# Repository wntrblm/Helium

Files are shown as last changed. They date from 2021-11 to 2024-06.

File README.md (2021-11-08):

# Winterbloom Helium

Helium is a precision buffered multiple and precision adder for Eurorack.

More details available at https://winterbloom.com/shop/helium

## Repository layout

This repository contains the hardware design files and user guide for Helium:

- **hardware/** contains the hardware design files for the mainboard and blank panel. These are all created using KiCAD.
- **user_guide/** contains the user's guide source files. These are written in Markdown and published using MkDocs.

## License and contributing

Helium is open-source hardware and software, however, licensing a project like this is a little complicated. Please take a chance to review the [LICENSE](LICENSE.md) file.

We welcome contributions! Please read our [Code of Conduct](CODE_OF_CONDUCT.md) first.

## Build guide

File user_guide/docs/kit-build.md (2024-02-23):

---
title: Kit build guide
---

# Build

Welcome to the build guide for Helium's DIY kit. We hope you have a great time putting this module together and a wonderful time using it.

Please **read all instructions** thoroughly before starting. If you have questions or run into trouble please reach out to us on [discord] or drop us an email at support@winterbloom.com.

Some soldering experience is helpful but not required. If it's your first time soldering we recommend reading through [Adafruit's guide to excellent soldering](https://learn.adafruit.com/adafruit-guide-excellent-soldering).

This build takes around **one hour** to complete.

[discord]: https://discord.gg/UpfqghQ

## Tools required

Before you begin, make sure that you've got:

-   Safety glasses. Yes, **really**. A pair like [these][safety glasses] are fine.
-   Proper ventilation, like this [small filtered fan](https://a.co/d/eUfPCRO).
-   A **temperature-controlled** soldering iron, like this [Hakko] or the [Pinecil]. It is very important to use a temperature-controlled iron, since unregulated irons can easily get hot enough to damage components. You should set your iron temperature based on your solder manufacturer's recommendations.
-   Solder. We recommend [Adafruit's SAC305 solder][adafruit solder] or [Kester 275 K100LD].

!!! question "Flux"
    We suggest using solder with "no clean" flux. If you use a different kind of flux, be sure to carefully clean the flux residue off based on the guidelines provided by the manufacturer of your solder. Take special care with the LEDs and potentiometers, as they can be damaged by water and flux cleaners.

[safety glasses]: https://a.co/d/dMXvPP6
[tweezers]: https://www.adafruit.com/product/422
[Hakko]: https://www.adafruit.com/product/1204
[Pinecil]: https://pine64.com/product/pinecil-smart-mini-portable-soldering-iron/
[adafruit solder]: https://www.adafruit.com/product/734
[Kester 275 K100LD]: https://www.kester.com/products/product/275-flux-cored-wire
[flux pen]: https://www.sra-solder.com/sra-312-no-clean-flux-pen-refillable

## Kit contents

Your kit should contain the following items. If any are missing please email us at support@winterbloom.com.

<winter-image-map src="../images/kit.svg">
    <winter-image-map-item id="mainboard">Mainboard</winter-image-map-item>
    <winter-image-map-item id="panel">Front panel</winter-image-map-item>
    <winter-image-map-item id="jacks">1/8" jacks (16)</winter-image-map-item>
    <winter-image-map-item id="nuts">Hex nuts for the 1/8" jacks (16)</winter-image-map-item>
    <winter-image-map-item id="power-header">Eurorack power header (1)</winter-image-map-item>
    <winter-image-map-item id="rubber-bands">Rubber bands (2)</winter-image-map-item>
</winter-image-map>

- (1) Mainboard
- (1) Front panel
- (16) 1/8" jacks
- (16) Hex nuts for the 1/8" jacks
- (1) Eurorack power header
- (2) Rubber bands

## Soldering the power header

Your first task is to place and solder the power header to the mainboard.

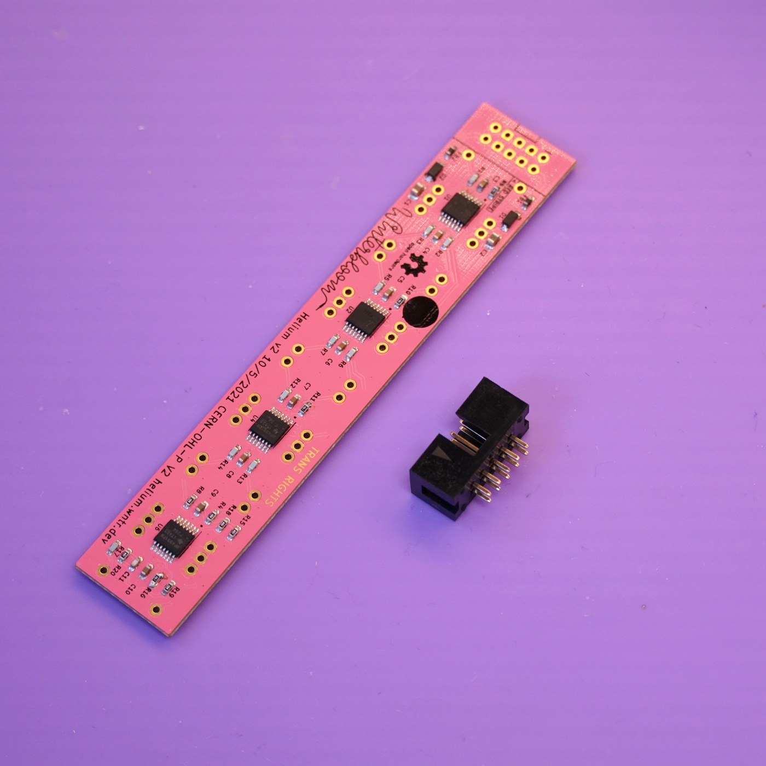
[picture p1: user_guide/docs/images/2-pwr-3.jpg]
The mainboard and power header


Place the power header onto the back side of the mainboard, being careful to align the notch in the header with the drawing on the board. The power header fits snugly, so you might have to give it a little pressure to push it all the way in.

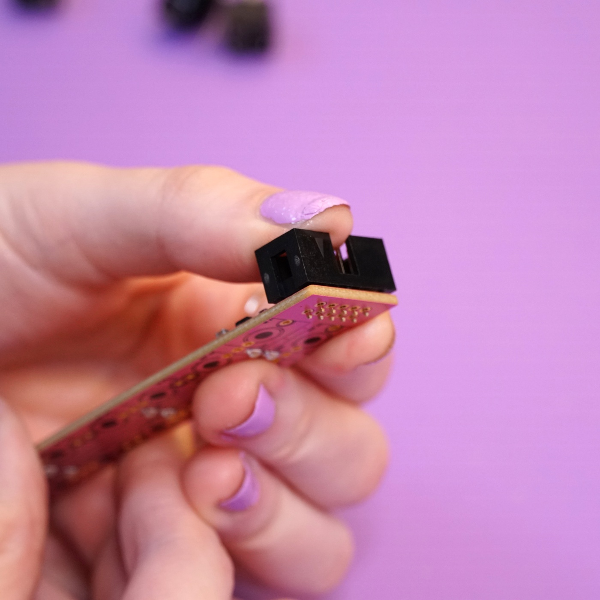
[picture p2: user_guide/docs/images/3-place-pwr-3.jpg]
The power header placed on to the mainboard


Flip the board over to the front side and solder the header's 10 pins.

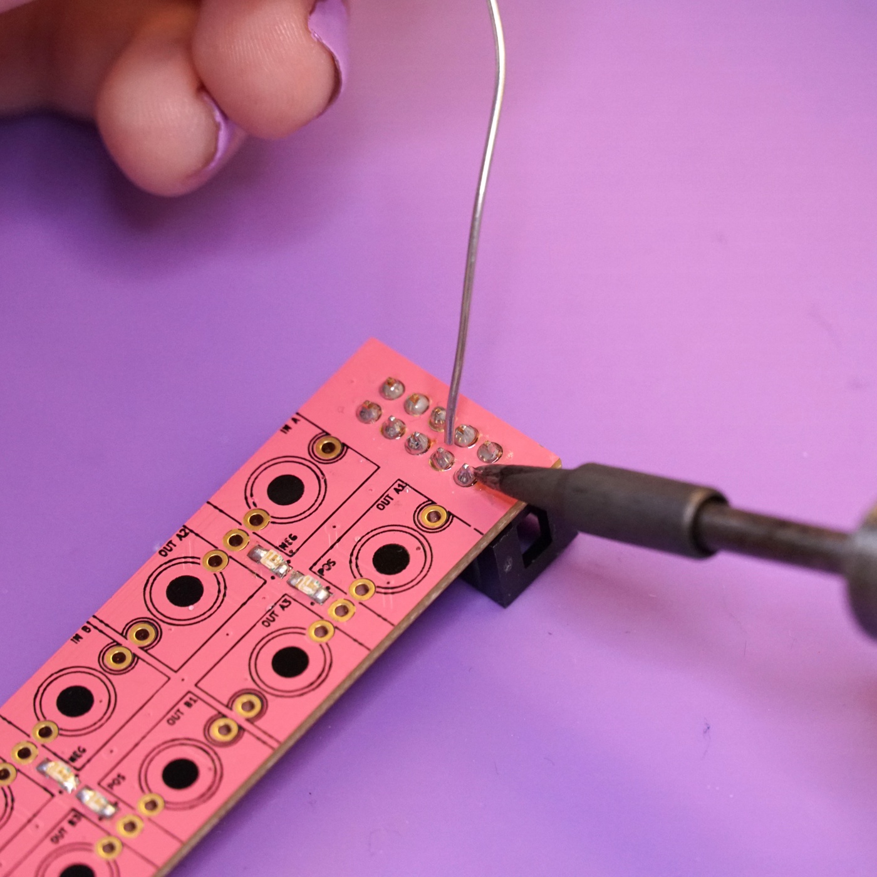
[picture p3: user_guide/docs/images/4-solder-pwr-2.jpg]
The power header being soldered to the mainboard


## Placing the jacks

Next up is placing the sixteen jacks on the front side of the mainboard. Start by placing the first jack on in the space labeled `In A`. Place it according to the drawing on the board, with the third, bendy leg going into the adjacent hole.

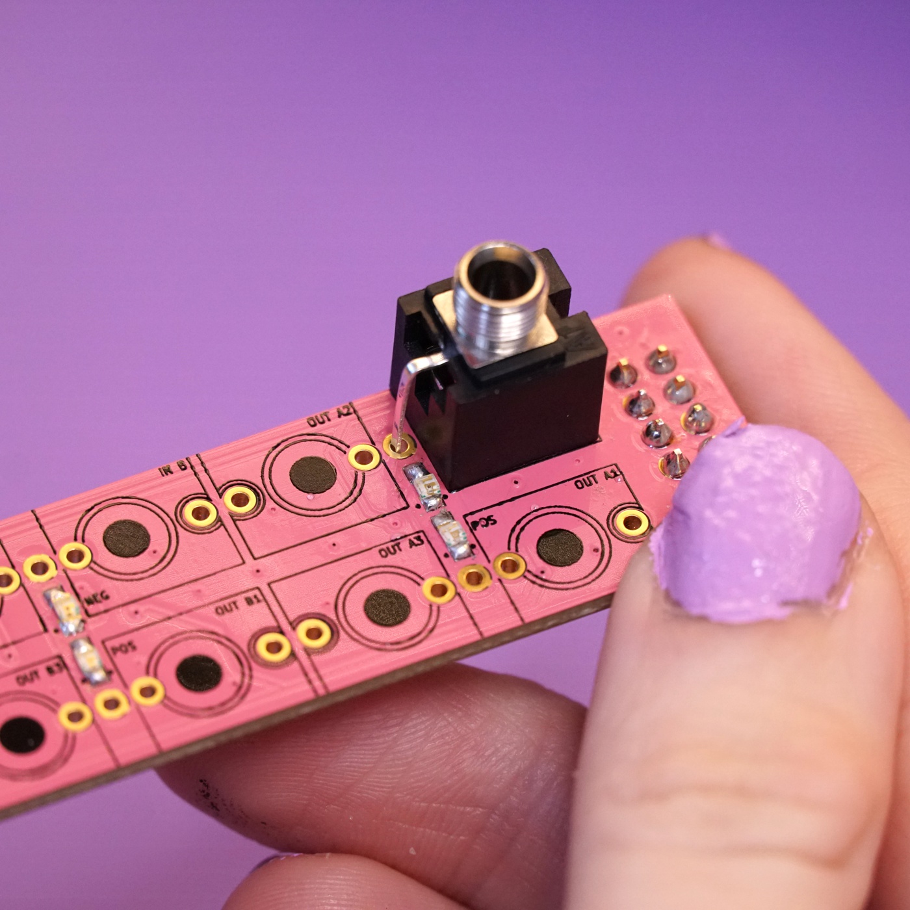
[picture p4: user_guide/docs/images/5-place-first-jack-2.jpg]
The first jack placed on the front side of the mainboard, over the place labeled "In A"


The second jack is a bit trickier. Place it into the space labeld `Out A2` but in the **opposite** orientation of the first jack. Place the third leg into the **same** hole as the first jack's third leg.

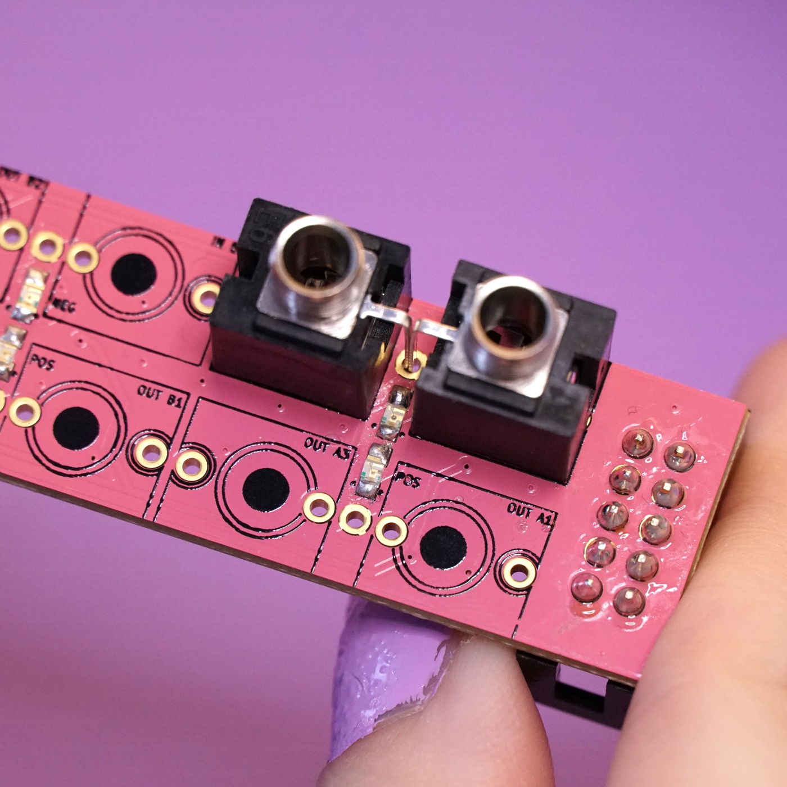
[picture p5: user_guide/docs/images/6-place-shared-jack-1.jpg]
The second jack placed on the front side of the mainboard, over the place labeled "Out A2", with its third leg sharing the same hole as the first jack


Continue this pattern for the third and fourth jacks in the spaces labeled `In B` and `Out B2`. The third and fourth jacks will have their third legs placed into the same hole.

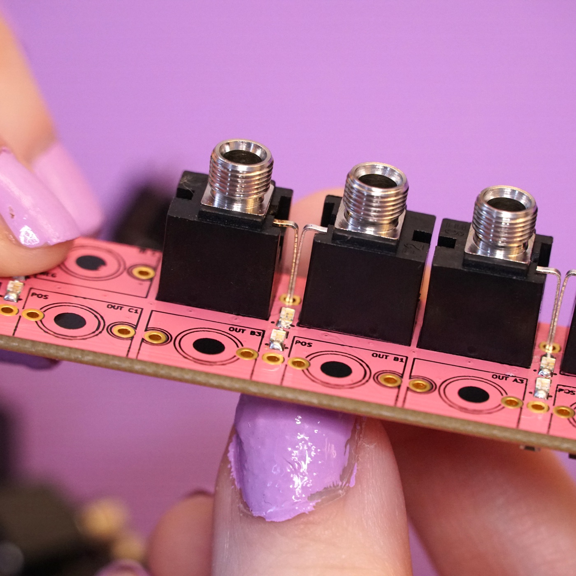
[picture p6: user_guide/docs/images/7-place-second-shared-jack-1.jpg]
The third and fourth jacks placed with them sharing a single hole for their third legs


Likewise for the remaining jacks. Continue the pattern of alternating orientation and sharing the hole for the third leg until all jacks are placed.

<winter-carousel>
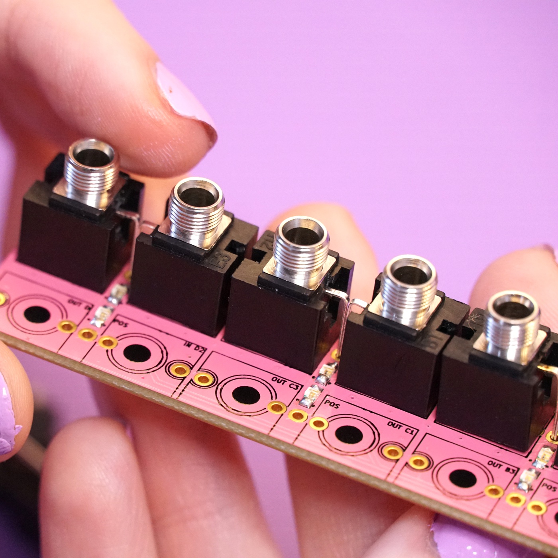
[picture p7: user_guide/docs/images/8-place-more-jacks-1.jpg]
The remaining jacks on the left side of the board all placed
    
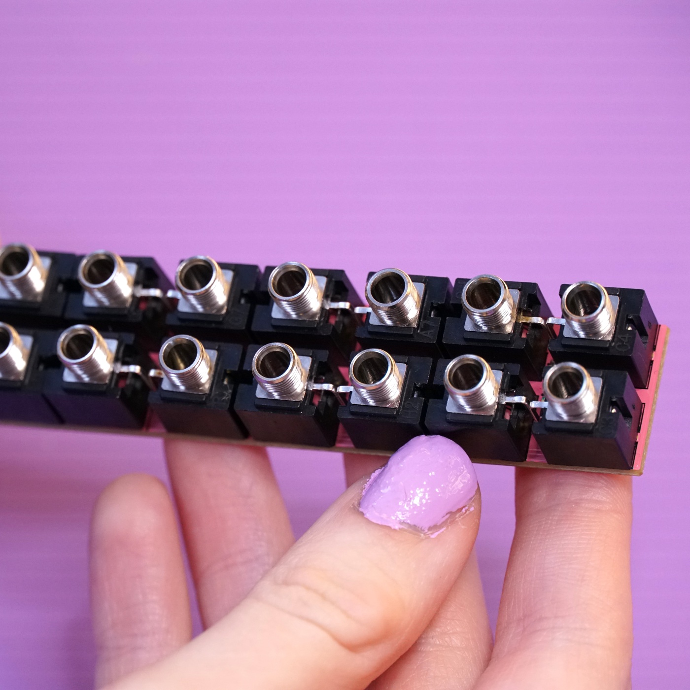
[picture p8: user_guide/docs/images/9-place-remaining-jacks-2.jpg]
All jacks on the board placed
    
</winter-carousel>

## Using the front panel as a jig

Since the jacks need to peek through the front panel, you can use it as a jig to make sure everything stays in the right place while soldering. Carefully line up the front panel's holes with the jacks and push the front panel on.

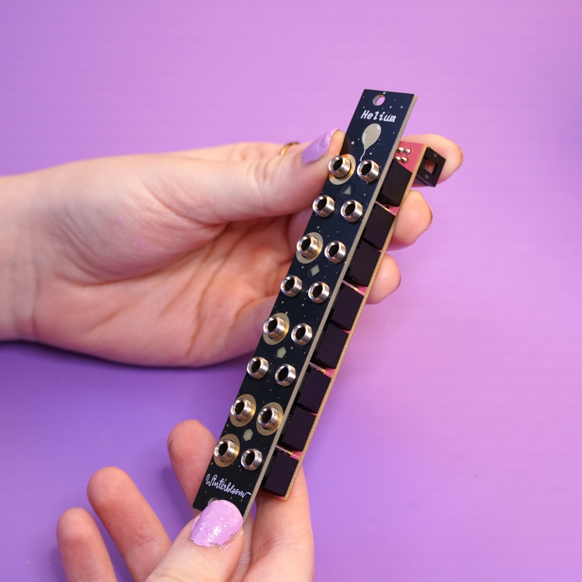
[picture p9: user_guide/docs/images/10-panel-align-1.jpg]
The front panel placed over the jacks


Then, use the two rubber bands to temporarily hold the front panel on while you're working on it. You'll need to double- or triple- over the rubber band to get it tight.

<winter-carousel>
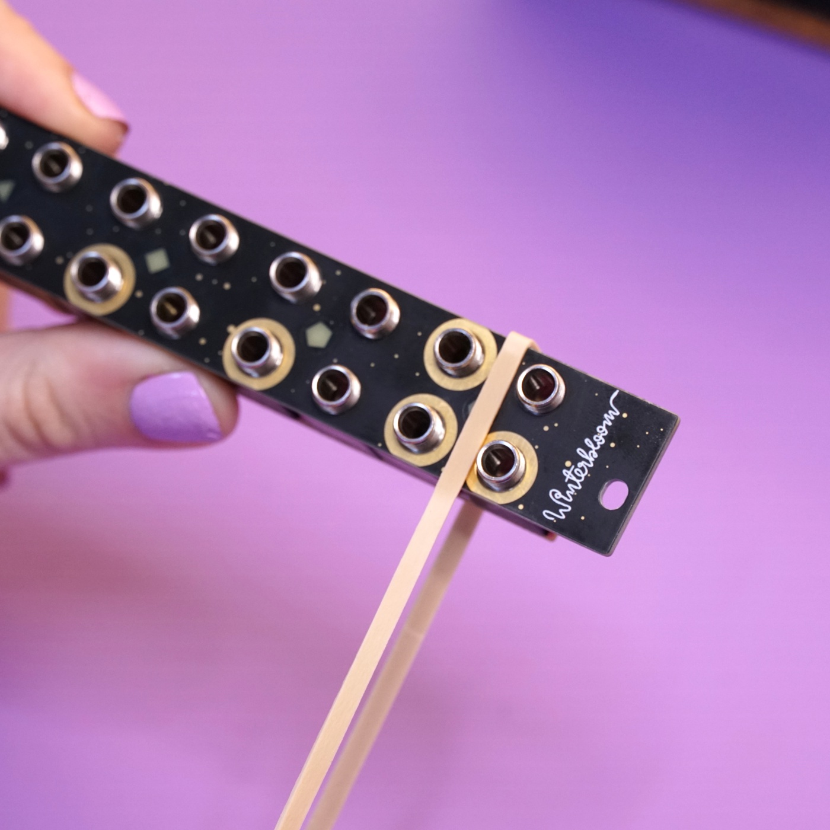
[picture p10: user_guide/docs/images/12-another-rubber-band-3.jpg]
A rubber band being pulled taught over one side of the module
    
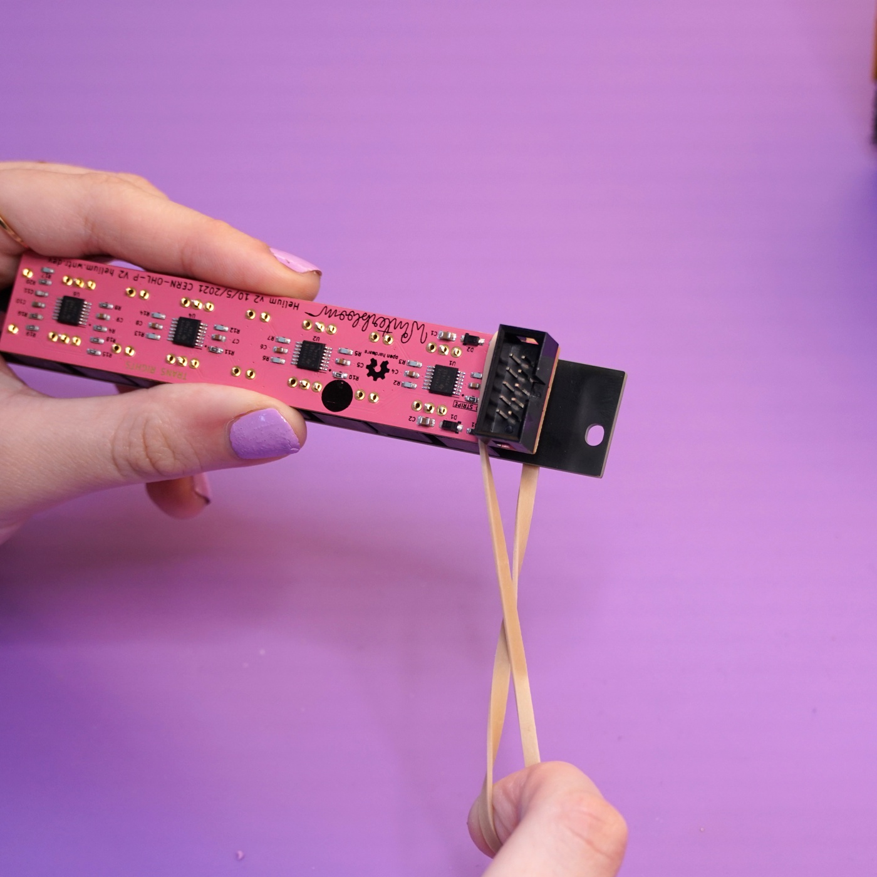
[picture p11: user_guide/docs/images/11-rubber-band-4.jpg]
The same rubber band being doubled over
    
</winter-carousel>

Put the two rubber bands on opposite sides of the module so that everything is held down snugly.

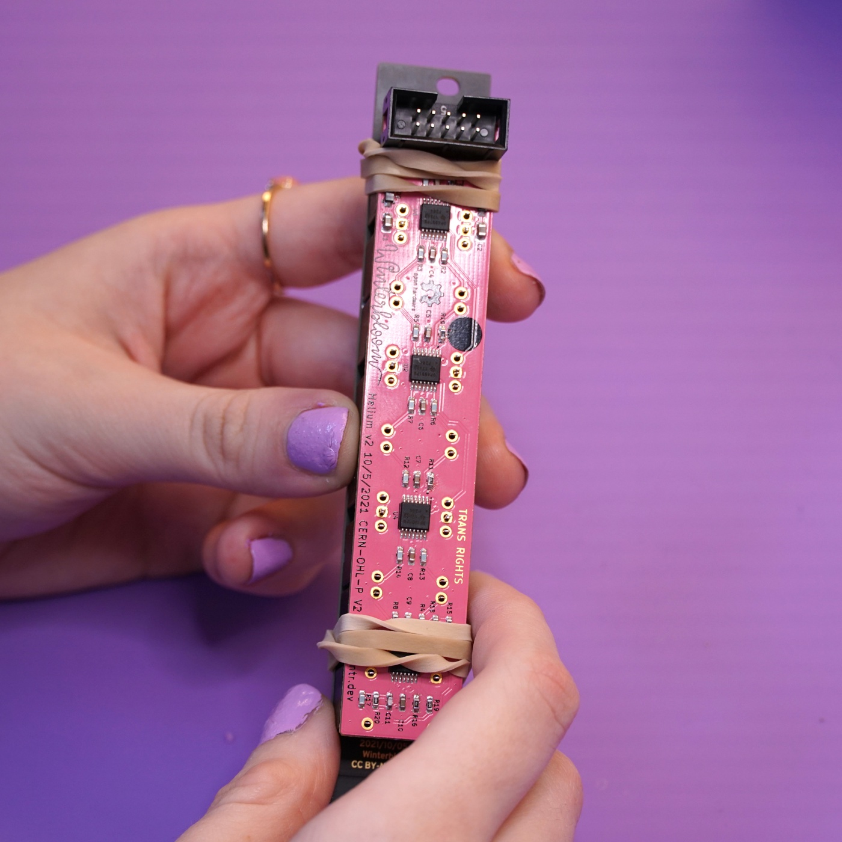
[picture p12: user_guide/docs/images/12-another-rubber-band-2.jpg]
Another rubber band has been placed on the other side of the module, firmly holding everything together


## Soldering the jacks

With everything held in place, you can now flip the module over and solder all of the jacks in place. As you go, take a moment now and then to check that everything is flush with the panel and mainboard.

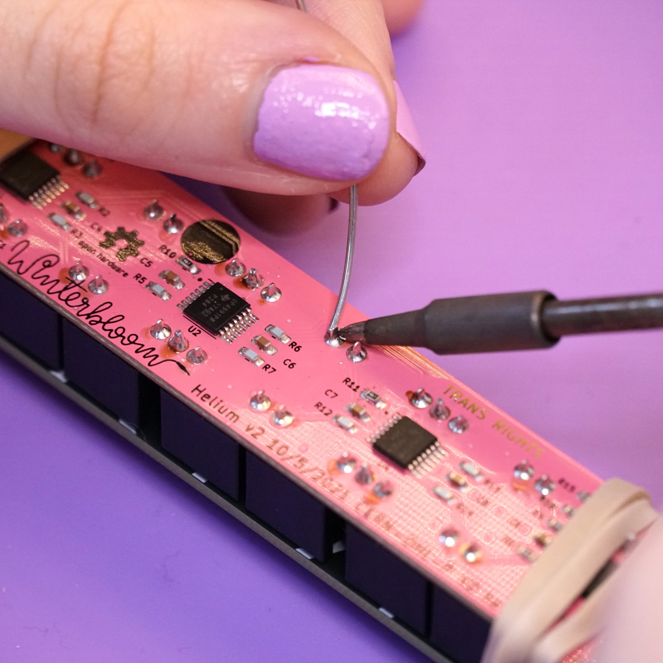
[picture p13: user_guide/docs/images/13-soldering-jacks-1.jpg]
The back side of the board is shown where one of the holes for the jacks is being soldered


Once you've got most of the soldering done, you can move the rubber bands out of the way to get to the holes that they were covering up. You won't need the rubber bands again after this step, so feel free to give those a new purpose in life somewhere else.

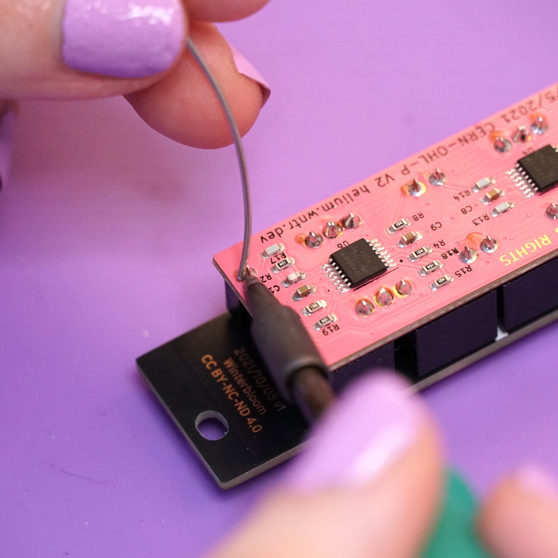
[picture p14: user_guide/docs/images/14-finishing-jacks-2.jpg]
The back side of the board is shown with the last hole for the jacks being soldered


## Putting the panel on

The last step it to place Helium's lovely panel on and secure it with the hex nuts. You don't need to over-tighten the hex nuts, finger-tight is fine.

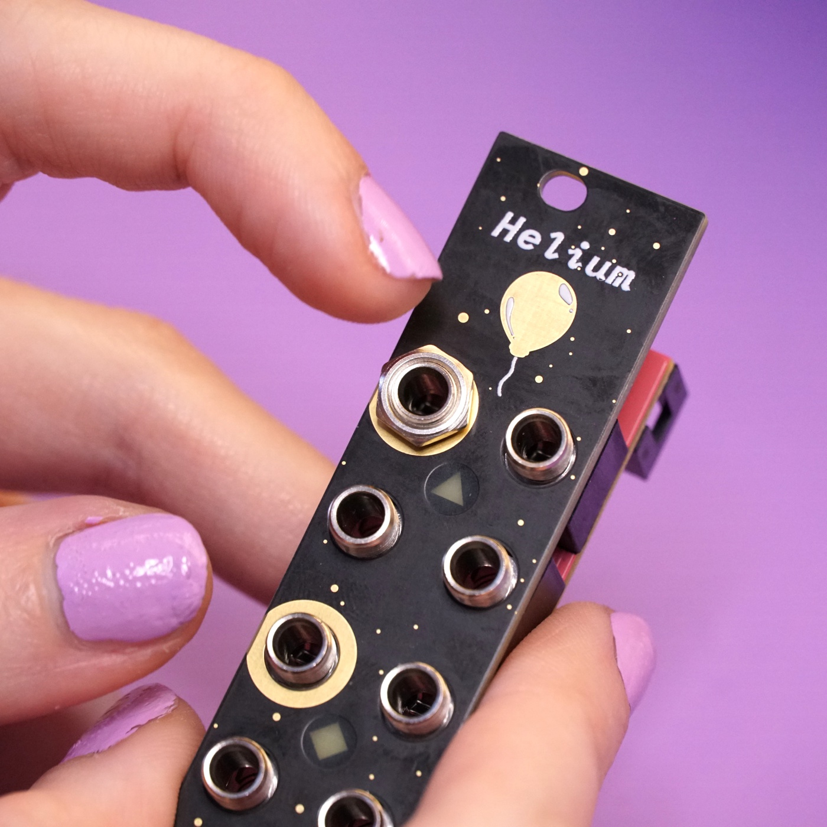
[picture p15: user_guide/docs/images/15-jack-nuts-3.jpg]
The module with the panel placed and one of the jack nuts being tightened in place


## All done

Congratulations! You've finished your very own Helium!

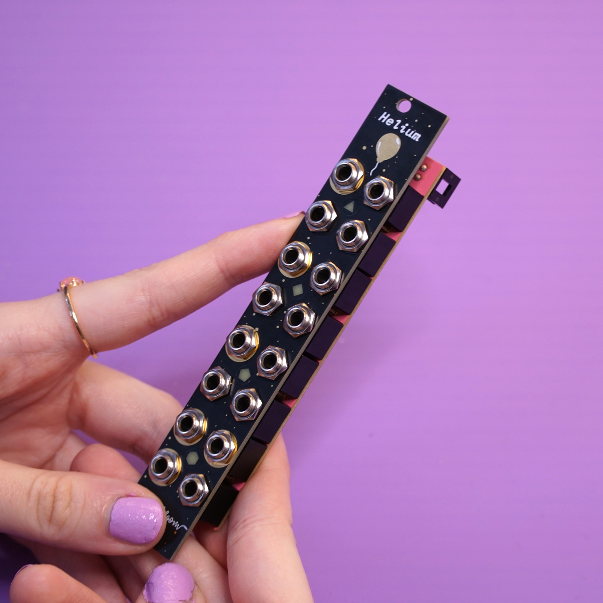
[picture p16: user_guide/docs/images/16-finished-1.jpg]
The compeleted module


Now that it's all put together go check out the [User's Guide](index.md) and please show us your work by tweeting at [@wntrblm](https://twitter.com/wntrblm) or tagging [@wntrblm](https://instagram.com/wntrblm) in your instagram post.

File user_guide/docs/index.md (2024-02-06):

# Helium User Guide

[Helium](https://winterbloom.com/shop/helium) is a precision, three channel, 1-to-3 buffered multiple and a 3-to-1 precision adder.

[TOC]

## Specifications

* Available [assembled](https://winterbloom.com/shop/helium) or as a [kit](https://winterbloom.com/shop/helium-kit)
* `6 HP`
* `+12v @ 35mA`, `-12v @ 35mA`
* `22mm` deep
* Three 1-to-3 chainable buffered multiples
* One 3-to-1 precision adder
* Low offset, low drift, low noise operational amplifiers used throughout, and the precision adder uses thin film resistors with 0.05% tolerance.
* [ModularGrid page](https://www.modulargrid.net/e/winterbloom-helium)

## Getting support and help

We want you to have a wonderful experience with your module. If you need help or run into problems, please reach out to us. [Email] is the best way for product issues, whereas [Discord] and [GitHub][github issues] are great for getting advice and help on how to customize your module.

-   Send us [an email][email]
-   File a bug [on GitHub][github issues]
-   Reach out on the [Discord][discord]

[github issues]: https://github.com/wntrblm/Neptune/issues
[discord]: https://discord.gg/UpfqghQ
[email]: mailto:support@winterbloom.com

## Installing the module

To install this into your Eurorack setup, connect a Eurorack power cable from your power supply to the back of the module. **Note that even though there's a keyed power connector on the module, double check that the red stripe is on the side labeled `red stripe`!** Once you've connected the power cable, secure your module to your rack rails using screws.

## Using the buffered multiples

Helium has three independent buffered multiples that each have three outputs. These are also called *unity gain buffers*.

Illustration of using Helium's three channels independently

Each channel's input is on the top left and the three buffered outputs follow on the right and below. The LEDs for each channel will glow blue for positive signals, red for negative signals, and purple for audio signals.

Additionally, the inputs for channel two and three are chained so if nothing is connected to the input then the input of the preceding channel is used. This allows you to use Helium to buffer a single signal to up to nine outputs.

Illustration of using Helium as a single channel, nine output buffer

## Using the precision adder

Helium has a precision adder with three inputs and one output. It sums the three inputs into a single output and works equally well for CV and audio signals. Precision adders are also called *unity gain mixers*.

Illustration of using Helium as a precision adder

The inputs are the top two and bottom left jacks (shown in teal, purple, and red) while the output is the bottom right jack (shown in yellow). Unconnected inputs do not affect the output. Just like with the buffered multiple channels, The LED in the middle will glow blue for positive signals, red for negative signals, and purple for audio signals (it's shown in yellow above for illustrative purposes).

That's pretty much it! ✨

## Open source hardware & software

Helium is completely open source and hacking is encouraged.

The [hardware designs](https://github.com/wntrblm/Helium/tree/main/hardware) is available under the permissive [CERN-OHL-P v2](https://cern-ohl.web.cern.ch/) and is designed using [KiCAD](https://kicad.org/) which is free and open-source. You can open the hardware files using KiCAD or you can [check out a PDF of the schematic](https://github.com/wntrblm/Helium/tree/main/hardware/board/board.pdf).

Open Source Hardware Association mark Helium is [certified open source hardware](https://certification.oshwa.org/us002071.html)

## Warranty, disclaimers, and limits

Modules purchased from Winterbloom have a warranty of six months from the date of purchase. This warranty covers any manufacturing defects in the module. It does not cover damage from due to incorrect handling, storage, or power, overvoltage events, or modifications.

Please [contact us](mailto:support@winterbloom.com) if you are experiencing issues with your module. Modules returned under warranty will either be refunded, replaced, or repaired at our discretion. You will be responsible for the cost of returning the module to Winterbloom.

Because Eurorack has a vast number of possible combinations of power supplies, modules, cases, and accessories, it is impossible for us to guarantee compatibility with every possible configuration. We make a reasonable effort to test modules with several power supplies, cases, and other modules.

We encourage tinkering, however, we will not refund, repair, or replace any products that have been modified.

We have stress tested Helium under the following conditions. These are provided for reference only; we do not guarantee that that the module will function under these conditions.

* Continuous run time: at least `48 hours`
* Overvoltage from power supply: at least `±18 V`
* Reverse voltage from power supply: at least `±18 V`
* Undervoltage from power supply: as low as `±6 V`
* Over and under voltage on inputs: at least `±12 V`
* Outputs shorted together: at least `30 minutes`
* Outputs shorted to ground: at least `30 minutes`

## Acknowledgments and thanks

Helium would not be possible without the support of Winterbloom's incredible community, the Trans Synth Discord, and Noise Engineering.

[discord]: https://discord.gg/UpfqghQ

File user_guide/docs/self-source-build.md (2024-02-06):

---
title: Self-sourcing build guide
---

# Helium self-sourcing build guide

Welcome to the guide for self-sourcing and building [Helium](index.md). This guide is for folks who want to build a Helium on their own from bare printed circuit boards and components.

[TOC]

## Overview

This process is not for the faint of heart! You'll need to find, purchase, assemble, and test everything yourself. If you just want to have fun putting together a kit, consider our [Helium DIY kit] which includes everything you need with a fully tested PCB that has all of the surface mount assembly done, leaving just the through-hole bits to you.

| | Self-source | DIY kit | Fully assembled |
| --- | --- | --- | --- |
| PCBs | ❌ | ✅ | ✅ |
| Faceplate | ❌ | ✅ | ✅ |
| Components | ❌ | ✅ | ✅ |
| Surface mount components soldered | ❌ | ✅ | ✅ |
| Fully tested | ❌ | ✅ | ✅ |
| Through hole components soldered  | ❌ | ❌ | ✅ |
| Difficulty | Expert | Easy | None! |

Please read **all instructions thoroughly before starting**. If you have questions or run into trouble please reach out to us on [discord] or drop us an email at support@winterbloom.com, though note that we have limited resources for supporting self-sourced builds.

With all that said, we hope you have a great time putting this module together and a wonderful time using it. Good luck!

[Helium DIY kit]: https://winterbloom.com/shop/helium-kit
[discord]: https://discord.gg/UpfqghQ

## Skills required

Building a Helium from scratch requires patience, care, and skill. Helium can be a great a project for learning these skills, but we do recommend being careful with some of the more expensive components. Though not strictly required, we recommend that you have:

-   Experience finding and buying components from major distributors such as [Digi-Key] or [Mouser].
-   Experience submitting and buying printed circuit boards (PCBs) from services such as [OSHPark] or [PCBWay].
-   Experience preparing Gerber plot files from [KiCAD] design files.
-   Experience soldering [0603] and [TSSOP-16] components- We recommend watching tutorials on how to drag solder, such as [this one from GreatScott!][drag-soldering], and practicing with an inexpensive [surface mount training board].

[Digi-Key]: https://digikey.com
[Mouser]: https://mouser.com
[OSHPark]: https://oshpark.com
[PCBWay]: https://pcbway.com
[KiCAD]: https://kicad.org
[0603]: https://en.wikipedia.org/wiki/File:SMT_sizes,_based_on_original_by_Zureks.svg
[TSSOP-16]: https://en.wikipedia.org/wiki/Thin_shrink_small_outline_package
[drag-soldering]: https://www.youtube.com/watch?v=VxMV6wGS3NY
[surface mount training board]: https://www.amazon.com/Gikfun-Beginner-Components-Practice-Soldering/dp/B01HPSRXJ0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

## Tools required

Before you begin, make sure that you've got:

-   Safety glasses. Yes, **really**. A pair like [these][safety glasses] are fine.
-   Proper ventilation, like this [small filtered fan](https://a.co/d/eUfPCRO).
-   [Tweezers].
-   A **temperature-controlled** soldering iron, like this [Hakko] or the [Pinecil]. It is very important to use a temperature-controlled iron, since unregulated irons can easily get hot enough to damage components. You should set your iron temperature based on your solder manufacturer's recommendations.
-   Solder. We suggest using soldering with "no clean" flux. If you do use a different kind of flux, be sure to carefully clean the flux residue off based on the guidelines provided by the manufacturer of your solder. For an inexpensive option, we recommend [Adafruit's SAC305 solder][adafruit solder], and for a higher-quality option we recommend [Kester 275 K100LD] (the same solder we use).
-   [Solder wick].
-   Flux, preferably no-clean flux, we recommend this [flux pen].
-   A magnifying glass or fantastic eyesight.

If you want to be extraordinarily well prepared:

-   A [hot air station] can be useful for undoing any soldering and is very helpful if you make a mistake like soldering a chip backwards.
-   A microscope. This can be useful for identifying any issues with soldering. A relatively inexpensive option is [this one][microscope].

[safety glasses]: https://a.co/d/dMXvPP6
[tweezers]: https://www.adafruit.com/product/422
[Hakko]: https://www.adafruit.com/product/1204
[Pinecil]: https://pine64.com/product/pinecil-smart-mini-portable-soldering-iron/
[adafruit solder]: https://www.adafruit.com/product/734
[Kester 275 K100LD]: https://www.kester.com/products/product/275-flux-cored-wire
[flux pen]: https://www.sra-solder.com/sra-312-no-clean-flux-pen-refillable
[solder wick]: https://www.adafruit.com/product/149
[hot air station]: https://www.adafruit.com/product/1869
[microscope]: https://www.amazon.com/Opti-Tekscope-Microscope-Advanced-Definition-Industrial/dp/B0184CCOY0

## Schematic

Though it's not required, you may find it useful to refer to Helium's schematic during your build. You can find it by downloading either:

* [The complete KiCAD project](https://github.com/wntrblm/Helium/tree/main/hardware/board)
* [A ready-to-print PDF](https://github.com/wntrblm/Helium/blob/main/hardware/board/board.pdf)

## PCB & faceplate

You'll need to source a printed circuit board (PCB) and faceplate for Helium. You have two options:

1. You can buy them directly [from Winterbloom][buy-boards]. These are extremely high quality boards built to our specifications. This is an especially good option if you live in the United States.
2. You can have them made for you by a PCB fab such as [OSHPark] or [PCBWay]. You'll generally receive multiple boards so this can be advantageous if you're planning on building several Heliums.

[buy-boards]: https://winterbloom.com/shop/helium-boards

If you choose to have a fab make your boards, you'll need to provide Gerber files for both the board and the faceplate.
We highly recommend preparing these from the [KiCAD] source files based on your fab's instructions. These can be found on GitHub:

-   Board: https://github.com/wntrblm/Helium/tree/main/hardware/board
-   Faceplate: https://github.com/wntrblm/Helium/tree/main/hardware/faceplate

However, you can also download pre-made Gerbers which should work for most fabs:

-   Board: https://github.com/wntrblm/Helium/blob/main/hardware/board/gerbers.zip
-   Faceplate: https://github.com/wntrblm/Helium/blob/main/hardware/faceplate/gerbers.zip

!!! note "Faceplate differences"
    The faceplate published on GitHub differs slightly from the faceplates sold by Winterbloom in that our logo has been removed.

We recommend giving your fab the following specifications:

-   Dimensions: `20 x 108 mm` (PCB) and `20 x 128.5 mm` (Faceplate)
-   Thickness: `1.6 mm`
-   Layers: 2
-   Min. track width: `0.2mm` / `7 mil`
-   Min. track spacing: `0.2 mm` / `7 mil`
-   Min. drill: `0.4 mm`
-   Soldermask: Matte black
-   Silkscreen: White
-   Surface finish: ENIG
-   Copper weight: `1 oz`
-   Substrate: FR4 TG 140 or better

!!! warning "Cheap fabs"
    There are many options for PCB fabs these days, but keep in mind that picking the absolute cheapest option does come at the cost of quality. Use with caution! If in doubt, just grab a PCB and faceplate from us.

If you're making multiple Heliums, we'd recommend picking up a [solder paste stencil] since it'll make assembly go a bit faster. Usually your PCB fab can provide them along with your boards.

[solder paste stencil]: https://www.pcbway.com/pcb_prototype/SMT_stencil_and_Laser_Stencil.html

## Bill of materials

Below is the bill of materials for Helium's electronic components, including part numbers and purchase links.

<div>
    <table class="is-page-width is-high-density">
        <thead>
            <tr>
                <th>Reference</th>
                <th>Value &amp; Rating</th>
                <th>Footprint</th>
                <th align="right">Qty</th>
                <th>Part no</th>
                <th>Digi-Key</th>
                <th>Mouser</th>
                <th>LCSC</th>
                <th align="right">Notes</th>
            </tr>
        </thead>
        <tbody>
            <tr>
                <td>C1, C2</td>
                <td>10µF<br/>25V/±10%/X5R</td>
                <td>0805</td>
                <td align="right">2</td>
                <td>Murata GRM21BR61E106KA73K</td>
                <td><a href="https://www.digikey.com/en/products?keywords=490-16824-1-ND" referrerpolicy="origin" rel="external noopener" target="_blank">490-16824-1-ND</a></td>
                <td><a href="https://www.mouser.com/c/?q=81-GRM21BR61E106KA3K" referrerpolicy="origin" rel="external noopener" target="_blank">81-GRM21BR61E106KA3K</a></td>
                <td><a href="https://www.lcsc.com/search?q=C3909351" referrerpolicy="origin" rel="external noopener" target="_blank">C3909351</a></td>
                <td align="right">5</td>
            </tr>
            <tr>
                <td>C3-C10</td>
                <td>100nF<br/>25V/±10%/X5R</td>
                <td>0603</td>
                <td align="right">8</td>
                <td>Samsung CL10B104KB8NNNC</td>
                <td><a href="https://www.digikey.com/en/products?keywords=1276-1000-2-ND" referrerpolicy="origin" rel="external noopener" target="_blank">1276-1000-2-ND</a></td>
                <td><a href="https://www.mouser.com/c/?q=187-CL10B104KB8NNNC" referrerpolicy="origin" rel="external noopener" target="_blank">187-CL10B104KB8NNNC</a></td>
                <td><a href="https://www.lcsc.com/search?q=C1591" referrerpolicy="origin" rel="external noopener" target="_blank">C1591</a></td>
                <td align="right">5</td>
            </tr>
            <tr>
                <td>C11</td>
                <td>18pF<br/>25V/±10%/C0G</td>
                <td>0603</td>
                <td align="right">1</td>
                <td>Yageo CC0603JPNPO9BN120</td>
                <td><a href="https://www.digikey.com/en/products?keywords=13-CC0603JPNPO9BN120CT-ND" referrerpolicy="origin" rel="external noopener" target="_blank">13-CC0603JPNPO9BN120CT-ND</a></td>
                <td><a href="https://www.mouser.com/c/?q=603-CC603JPNPO9BN120" referrerpolicy="origin" rel="external noopener" target="_blank">603-CC603JPNPO9BN120</a></td>
                <td><a href="https://www.lcsc.com/search?q=C1853092" referrerpolicy="origin" rel="external noopener" target="_blank">C1853092</a></td>
                <td align="right">5</td>
            </tr>
            <tr>
                <td>R1-R3, R5-R7, R12-R14, R17</td>
                <td>51Ω 100mW/±1%/Thin</td>
                <td>0603</td>
                <td align="right">10</td>
                <td>Yageo RT0603FRE0751RL</td>
                <td><a href="https://www.digikey.com/en/products?keywords=13-RT0603FRE0751RLCT-ND" referrerpolicy="origin" rel="external noopener" target="_blank">13-RT0603FRE0751RLCT-ND</a></td>
                <td><a href="https://www.mouser.com/c/?q=603-RT0603FRE0751RL" referrerpolicy="origin" rel="external noopener" target="_blank">603-RT0603FRE0751RL</a></td>
                <td><a href="https://www.lcsc.com/search?q=C849799" referrerpolicy="origin" rel="external noopener" target="_blank">C849799</a></td>
                <td align="right">5</td>
            </tr>
            <tr>
                <td>R4, R8, R15, R18-R20</td>
                <td>100kΩ<br/>100mW/±0.05%/Thin</td>
                <td>0603</td>
                <td align="right">6</td>
                <td>Susumu RG1608N-104-W-T1</td>
                <td><a href="https://www.digikey.com/en/products?keywords=RG16N100KWCT-ND" referrerpolicy="origin" rel="external noopener" target="_blank">RG16N100KWCT-ND</a></td>
                <td><a href="https://www.mouser.com/c/?q=754-RG1608N-104-W-T1" referrerpolicy="origin" rel="external noopener" target="_blank">754-RG1608N-104-W-T1</a></td>
                <td><a href="https://www.lcsc.com/search?q=C1722256" referrerpolicy="origin" rel="external noopener" target="_blank">C1722256</a></td>
                <td align="right">1</td>
            </tr>
            <tr>
                <td>R9-R11, R16</td>
                <td>1.5kΩ<br/>100mW/±5%/Thick</td>
                <td>0603</td>
                <td align="right">4</td>
                <td>Yageo RC0603JR-071K5L</td>
                <td><a href="https://www.digikey.com/en/products?keywords=311-1.5KGRCT-ND" referrerpolicy="origin" rel="external noopener" target="_blank">311-1.5KGRCT-ND</a></td>
                <td><a href="https://www.mouser.com/c/?q=603-RC0603JR-071K5L" referrerpolicy="origin" rel="external noopener" target="_blank">603-RC0603JR-071K5L</a></td>
                <td><a href="https://www.lcsc.com/search?q=C114680" referrerpolicy="origin" rel="external noopener" target="_blank">C114680</a></td>
                <td align="right">5</td>
            </tr>
            <tr>
                <td>FB1, FB2</td>
                <td>1kΩ @ 100MHz<br/>300mA</td>
                <td>0603</td>
                <td align="right">2</td>
                <td>Murata BLM18AG102SN1D</td>
                <td><a href="https://www.digikey.com/en/products?keywords=490-1015-1-ND" referrerpolicy="origin" rel="external noopener" target="_blank">490-1015-1-ND</a></td>
                <td><a href="https://www.mouser.com/c/?q=81-BLM11A102S" referrerpolicy="origin" rel="external noopener" target="_blank">81-BLM11A102S</a></td>
                <td><a href="https://www.lcsc.com/search?q=C85824" referrerpolicy="origin" rel="external noopener" target="_blank">C85824</a></td>
                <td align="right">6</td>
            </tr>
            <tr>
                <td>D1, D2</td>
                <td>Schottky<br/>30V/500mA</td>
                <td>SOD-123</td>
                <td align="right">2</td>
                <td>Nexperia PMEG2005EGWX</td>
                <td><a href="https://www.digikey.com/en/products?keywords=1727-7329-1-ND" referrerpolicy="origin" rel="external noopener" target="_blank">1727-7329-1-ND</a></td>
                <td><a href="https://www.mouser.com/c/?q=841-PMEG2005EGWX" referrerpolicy="origin" rel="external noopener" target="_blank">841-PMEG2005EGWX</a></td>
                <td><a href="https://www.lcsc.com/search?q=C133636" referrerpolicy="origin" rel="external noopener" target="_blank">C133636</a></td>
                <td align="right">4</td>
            </tr>
            <tr>
                <td>D3, D5, D7, D9</td>
                <td>Positive LED<br/>Blue/3.3V/20mA</td>
                <td>0805</td>
                <td align="right">4</td>
                <td>Kingbright APT2012VBC/D</td>
                <td><a href="https://www.digikey.com/en/products?keywords=754-1794-1-ND" referrerpolicy="origin" rel="external noopener" target="_blank">754-1794-1-ND</a></td>
                <td><a href="https://www.mouser.com/c/?q=604-APT2012VBC/D" referrerpolicy="origin" rel="external noopener" target="_blank">604-APT2012VBC/D</a></td>
                <td><a href="https://www.lcsc.com/search?q=C5879386" referrerpolicy="origin" rel="external noopener" target="_blank">C5879386</a></td>
                <td align="right">2</td>
            </tr>
            <tr>
                <td>D4, D6, D8, D10</td>
                <td>Positive LED<br/>Red/3.3V/20mA</td>
                <td>0805</td>
                <td align="right">4</td>
                <td>Kingbright APT2012VBC/D</td>
                <td><a href="https://www.digikey.com/en/products?keywords=754-1133-1-ND" referrerpolicy="origin" rel="external noopener" target="_blank">754-1133-1-ND</a></td>
                <td><a href="https://www.mouser.com/c/?q=604-APT2012SURCK" referrerpolicy="origin" rel="external noopener" target="_blank">604-APT2012SURCK</a></td>
                <td><a href="https://www.lcsc.com/search?q=C5875730" referrerpolicy="origin" rel="external noopener" target="_blank">C5875730</a></td>
                <td align="right">2</td>
            </tr>
            <tr>
                <td>U1, U2, U4, U6</td>
                <td>OPA4991</td>
                <td>TSSOP-14</td>
                <td align="right">4</td>
                <td>TI OPA4991IPWR</td>
                <td><a href="https://www.digikey.com/en/products?keywords=296-OPA4991IPWRCT-ND" referrerpolicy="origin" rel="external noopener" target="_blank">296-OPA4991IPWRCT-ND</a></td>
                <td><a href="https://www.mouser.com/c/?q=595-OPA4991IPWR" referrerpolicy="origin" rel="external noopener" target="_blank">595-OPA4991IPWR</a></td>
                <td><a href="https://www.lcsc.com/search?q=C2873620" referrerpolicy="origin" rel="external noopener" target="_blank">C2873620</a></td>
                <td align="right">2</td>
            </tr>
            <tr>
                <td>J1</td>
                <td>2x5 2.54mm<br/>IDC Header</td>
                <td>-</td>
                <td align="right">1</td>
                <td>On-shore 302-S101</td>
                <td><a href="https://www.digikey.com/en/products?keywords=ED1543-ND" referrerpolicy="origin" rel="external noopener" target="_blank">ED1543-ND</a></td>
                <td><a href="https://www.mouser.com/c/?q=710-61201021621" referrerpolicy="origin" rel="external noopener" target="_blank">710-61201021621</a></td>
                <td><a href="https://www.lcsc.com/search?q=C429962" referrerpolicy="origin" rel="external noopener" target="_blank">C429962</a></td>
                <td align="right"></td>
            </tr>
            <tr>
                <td>J2-J5, J7-J10, J12-J15, J17-J20</td>
                <td>Audio jack</td>
                <td>-</td>
                <td align="right">16</td>
                <td>WQP-WQP518MA</td>
                <td colspan="3">Available from <a href="https://winterbloom.com/shop/eurorack-jacks" referrerpolicy="origin" rel="external noopener" target="_blank">Winterbloom</a> or <a href="https://www.thonk.co.uk/shop/thonkiconn/" referrerpolicy="origin" rel="external noopener" target="_blank">Thonk</a></td>
                <td align="right"></td>
            </tr>
        </tbody>
    </table>
</div>

Notes:

1. If you are trying to reduce costs, you can swap the expensive `100kΩ 0.05%` resistors for much more affordable `0.1%` or `0.5%` resistors at the cost of reduced accuracy in the voltage adder circuit.
2. You can also swap the expensive OPA4991 op-amp with a more affordable alternative, such as OPA4171, OPA1679, or OPA4197. We don't recommend going with TL074 due to it exhibiting phase reversal.
3. The LEDs are known to work well with the faceplate's FR4 "diffusers" when using at most `10 mA`. If you use different LEDs, try to get them around `200 mcd @ 20 mA`. You can adjust their brightness & current consumption by changing the `1.5kΩ` resistors.
4. The two Schottky Barrier Diodes can generally be swapped for any `SOD-123` or `SOD-123F` Schottky with a reverse voltage V~R~ ≥ `20 V`, a forward current of I~F~ ≥ `500 mA`, and a forward voltage V~F~ ≤ `400 mV`. Most other `PMEGxxxxEG` parts work well.
5. Passive components such as resistors and capacitors often fluctuate in stock. They can be substituted with equivalent parts as specified by their **rating**. For capacitors, the rating is `Voltage/Tolerance/Dielectric`, for example `24V/±10%/C0G`. For resistors, the rating is `Power/Tolerance/Composition`, for example `100mW/±1%/Thin`. If part of the rating is left off, then it doesn't matter.
6. The ferrite beads can be swapped with similar `0603` ferrites with a DC current rating of ≥ `300 mA`. The ones we use have an impedance of `1 kΩ @ 100 MHz`.

## Component orientation

Before you start placing components, take a chance to note the correct orientation for components such as diodes, LEDs, large capacitors, and ICs.

For LEDs and diodes, the PCB and the components have corresponding cathode marks on one side. LEDs typically have a green marks on the top and a green triangle on the bottom, whereas diodes have a lighter stripe drawn across one side.

<div class="columns">
    <div class="column">
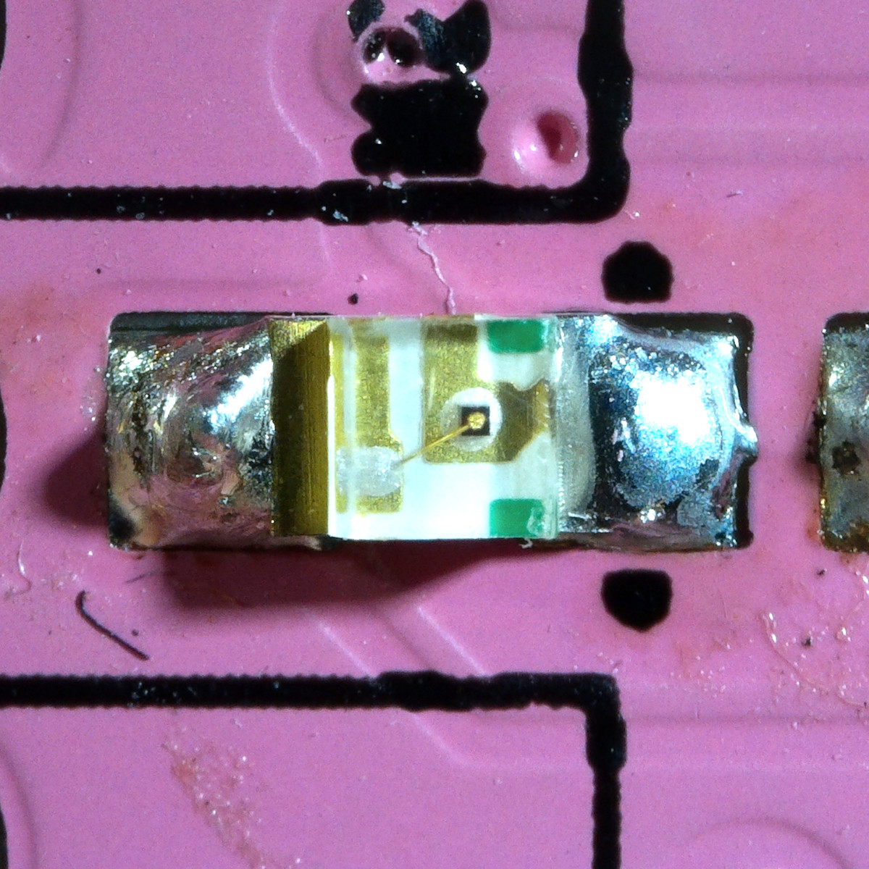
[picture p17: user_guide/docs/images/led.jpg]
A photo showing the proper alignment of LEDs
        
    </div>
    <div class="column">
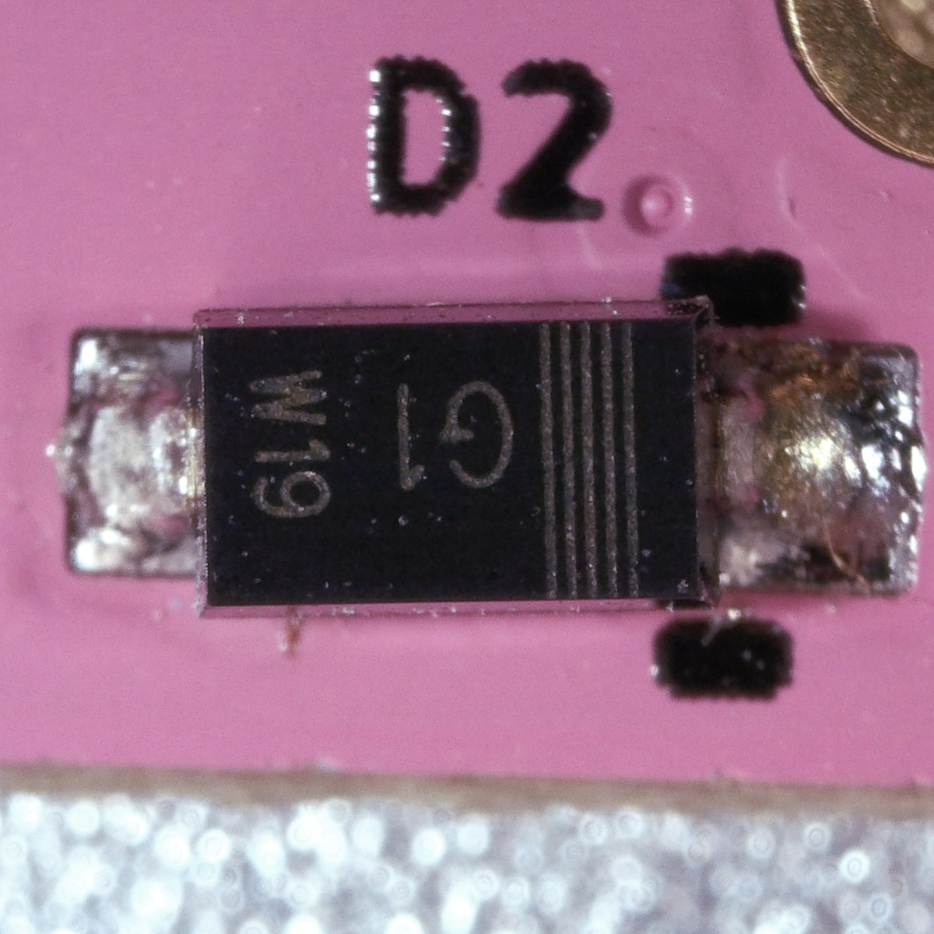
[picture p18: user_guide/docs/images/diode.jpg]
A photo showing the proper alignment of diodes
        
    </div>
</div>

Use additional caution soldering LEDs, as overheating them or melting their lens can destroy them.

Integrated circuits (ICs) also must be installed in the correct orentation. Most larger ICs have a circle in one corner that designates pin `1`. This should be matched with corresponding black circle or star on the board. The assembly diagrams [below](#assembly) also highlight pin `1` in <strong style="color:green;">green</strong>.

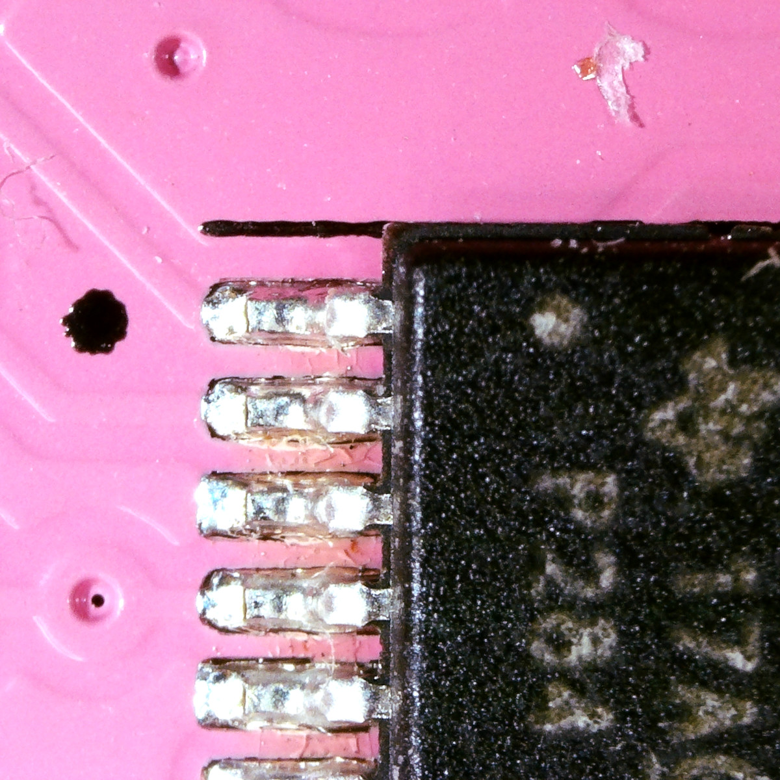
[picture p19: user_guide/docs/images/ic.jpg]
IC alignment


If in doubt, double check the chip's datasheet.

## Assembly

Helium has components on both sides of its board. We recommend starting with the back and then doing the front, since the majority of components are on the back. This is especially true if you're using a stencil and solder paste instead of an iron, as you'll want to be able to reflow the boards before placing the LEDs on the front side. We recommend that you start with the largest components first and work your way down to the small passives.

The interactive tables and images below show where to place each component.

-   Components are grouped by value so that you can work with one strip of components at a time.
-   **Click** on a row to highlight components on the PCB image.
-   Use the checkboxes to keep track of which components you've finished.

<winter-pcb-assembly src="/pcb-data.json" rotate></winter-pcb-assembly>

## Inspection & cleaning

Before moving on, take a moment to carefully inspect the PCB. Keep an eye out for:

* Missing components
* [Component orientation](#polarized-components)
* [Poor solder joints]
* [Solder bridges] between adjacent pins on ICs and between passives and nearby through holes
* The LEDs on the front side, since they will be very difficult to access once you add the jacks.

This is also a good chance to clean your board. We highly suggest following the instructions for your solder and flux. If in doubt, isopropyl alcohol and a cotton swab can be used to remove flux residue but look out for no-clean flux as it can turn sticky if not completely removed when exposed to alcohol.

[Poor solder joints]: https://www.protoexpress.com/blog/ipc-j-std-001-standard-soldering-requirements/
[Solder bridges]: https://electronics.stackexchange.com/questions/318164/how-do-i-prevent-bridges-while-soldering-smd-components

## Next steps

Congratulations, you have completed the hardest part! All that remains is assembling the through-hole components and putting on the faceplate. You can follow the [kit build guide](kit-build.md) to finish up.

## Support us

We made everything open source and put together this guide because we want you to be able to build, repair, and truly own your Helium. We don't expect anything in return, but if you'd like to show us some support feel free to:

- Give us a shoutout when you show off your work! We're on [Twitter] and [Instagram].
- Order something cute & soft from our [Threadless shop].
- Drop us a one-time tip through [Ko-fi] or [GitHub Sponsors].

[Twitter]: https://twitter.com/wntrblm
[Instagram]: https://instagram.com/wntrblm
[Threadless shop]: https://winterbloom.threadless.com/
[Ko-fi]: https://ko-fi.com/theacodes
[GitHub Sponsors]: https://github.com/sponsors/theacodes

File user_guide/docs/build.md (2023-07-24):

---
title: Kit build guide
---

# Helium kit build guide

Welcome to the build guide for Helium's DIY kit. We hope you have a great time putting this module together and a wonderful time using it.

Please **read all instructions** thoroughly before starting. If you have questions or run into trouble please reach out to us on [discord] or drop us an email at support@winterbloom.com.

If you purchased the surface mount kit, head over to the [surface mount kit build guide](/surface-mount-build) before going through this one.

Some soldering experience is helpful but not required. If it's your first time soldering we recommend reading through [Adafruit's guide to excellent soldering](https://learn.adafruit.com/adafruit-guide-excellent-soldering).

This build takes around **one hour** to complete.

[discord]: https://discord.gg/UpfqghQ

## Tools and materials required

Before jumping in, make sure you have:

* Safety glasses. Yes, really.
* Proper ventilation- at least open a window or two.
* A soldering iron, like [this one](https://www.adafruit.com/product/180).
* Solder, we can recommend [Adafruit's 60/40 **no-clean** rosin core solder](https://www.adafruit.com/product/145). We suggest using soldering with "no clean" flux. If you do use a different kind of flux, be sure to carefully clean the flux residue off based on the guidelines provided by the manufacturer of your solder.

## Kit contents

Your kit should contain the following items. If any are missing please email us at support@winterbloom.com.

<object
    alt="Kit contents"
    data-is-svg-map
    data-list="kit-contents-img-datalist"
    data-stylesheet="/styles/kit-contents-svgmap.css"
    data-info-text-template="kit-contents-img-info-text"
    data="../images/kit.svg"
    height="100%"
    id="kit-contents-img"
    type="image/svg+xml"
    width="100%">
</object>
<template id="kit-contents-img-info-text">
    <g id="info-text-container">
        <rect data-size-to="info-text"></rect>
        <text id="info-text"></text>
    </g>
</template>
<datalist id="kit-contents-img-datalist">
    <option value="mainboard">Mainboard</option>
    <option value="panel">Front panel</option>
    <option value="jacks">1/8" jacks (16)</option>
    <option value="nuts">Hex nuts for the 1/8" jacks (16)</option>
    <option value="power-header">Eurorack power header (1)</option>
    <option value="rubber-bands">Rubber bands (2)</option>
</datalist>
<script type="module" src="/scripts/svgmap.js"></script>
<link rel="stylesheet" href="/styles/svgmap.css"/>

- (1) Mainboard
- (1) Front panel
- (16) 1/8" jacks
- (16) Hex nuts for the 1/8" jacks
- (1) Eurorack power header
- (2) Rubber bands

## Soldering the power header

Your first task is to place and solder the power header to the mainboard.

The mainboard and power header

Place the power header onto the back side of the mainboard, being careful to align the notch in the header with the drawing on the board. The power header fits snugly, so you might have to give it a little pressure to push it all the way in.

The power header placed on to the mainboard

Flip the board over to the front side and solder the header's 10 pins.

The power header being soldered to the mainboard

## Placing the jacks

Next up is placing the sixteen jacks on the front side of the mainboard. Start by placing the first jack on in the space labeled `In A`. Place it according to the drawing on the board, with the third, bendy leg going into the adjacent hole.

The first jack placed on the front side of the mainboard, over the place labeled "In A"

The second jack is a bit trickier. Place it into the space labeld `Out A2` but in the **opposite** orientation of the first jack. Place the third leg into the **same** hole as the first jack's third leg.

The second jack placed on the front side of the mainboard, over the place labeled "Out A2", with its third leg sharing the same hole as the first jack

Continue this pattern for the third and fourth jacks in the spaces labeled `In B` and `Out B2`. The third and fourth jacks will have their third legs placed into the same hole.

The third and fourth jacks placed with them sharing a single hole for their third legs

Likewise for the remaining jacks. Continue the pattern of alternating orientation and sharing the hole for the third leg until all jacks are placed.

The remaining jacks on the left side of the board all placed
All jacks on the board placed

## Using the front panel as a jig

Since the jacks need to peek through the front panel, you can use it as a jig to make sure everything stays in the right place while soldering. Carefully line up the front panel's holes with the jacks and push the front panel on.

The front panel placed over the jacks

Then, use the two rubber bands to temporarily hold the front panel on while you're working on it. You'll need to double- or triple- over the rubber band to get it tight.

A rubber band being pulled taught over one side of the module
The same rubber band being doubled over

Put the two rubber bands on opposite sides of the module so that everything is held down snugly.

Another rubber band has been placed on the other side of the module, firmly holding everything together

## Soldering the jacks

With everything held in place, you can now flip the module over and solder all of the jacks in place. As you go, take a moment now and then to check that everything is flush with the panel and mainboard.

The back side of the board is shown where one of the holes for the jacks is being soldered

Once you've got most of the soldering done, you can move the rubber bands out of the way to get to the holes that they were covering up. You won't need the rubber bands again after this step, so feel free to give those a new purpose in life somewhere else.

The back side of the board is shown with the last hole for the jacks being soldered

## Putting the panel on

The last step it to place Helium's lovely panel on and secure it with the hex nuts. You don't need to over-tighten the hex nuts, finger-tight is fine.

The module with the panel placed and one of the jack nuts being tightened in place

## All done

Congratulations! You've finished your very own Helium!

The compeleted module

Now that it's all put together go check out the [User's Guide](/) and please show us your work by tweeting at [@wntrblm](https://twitter.com/wntrblm) or tagging [@wntrblm](https://instagram.com/wntrblm) in your instagram post.

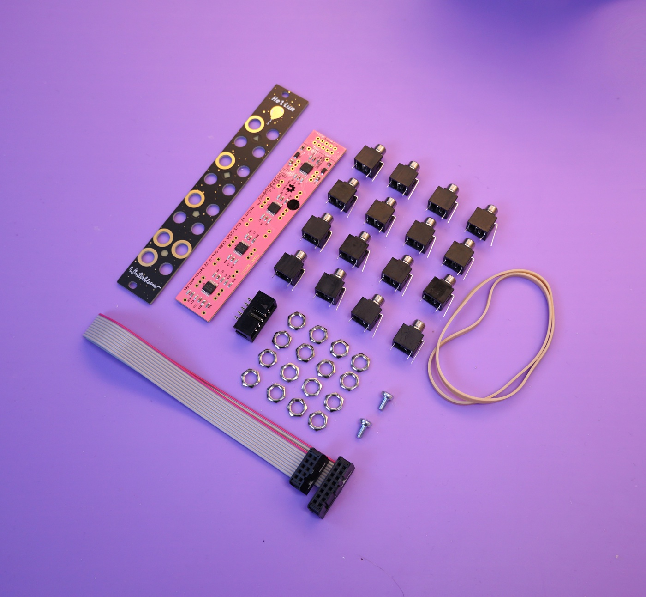
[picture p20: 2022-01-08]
user_guide/docs/images/1-kit-1.jpg

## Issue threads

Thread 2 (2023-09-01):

panel file

sputtering, 2023-09-01:
According to the Licence file, it seems to indicate that under the _hardware_ folder should be a panel folder (or file). I was not able to find the panel file there, nor anywhere in the repository. Am I not looking in the right area?

Just for context, in the future, I was going to get a Helium kit to assemble, and then make my own custom panel to use.

theacodes, 2023-11-30:
@sputtering I have no idea how I missed this for so long, my apologies

The faceplate files have been added, but even better, I've added a full [self sourcing guide](https://helium.wntr.dev/self-source-build/) and you can also buy bare PCBs and faceplates from [us](https://winterbloom.com/shop/helium-boards)

💜

Closed 2023-11-30.

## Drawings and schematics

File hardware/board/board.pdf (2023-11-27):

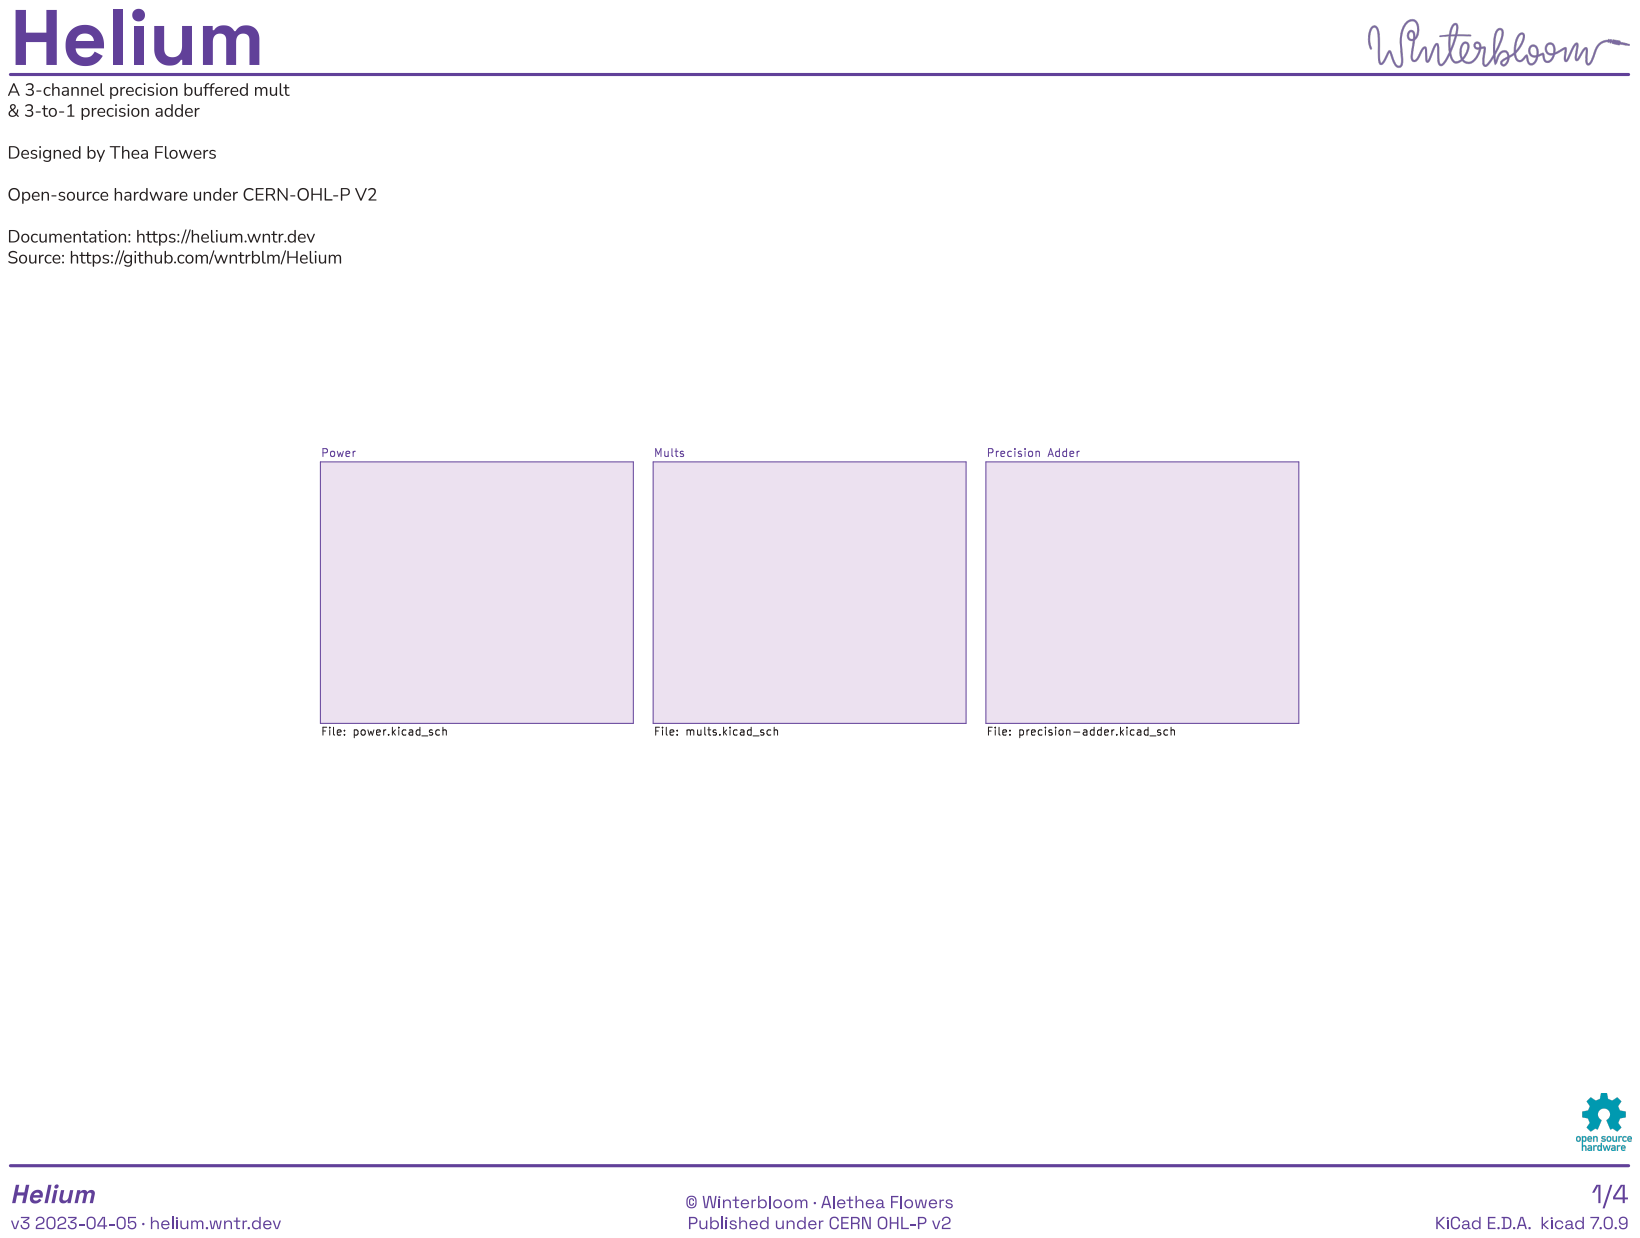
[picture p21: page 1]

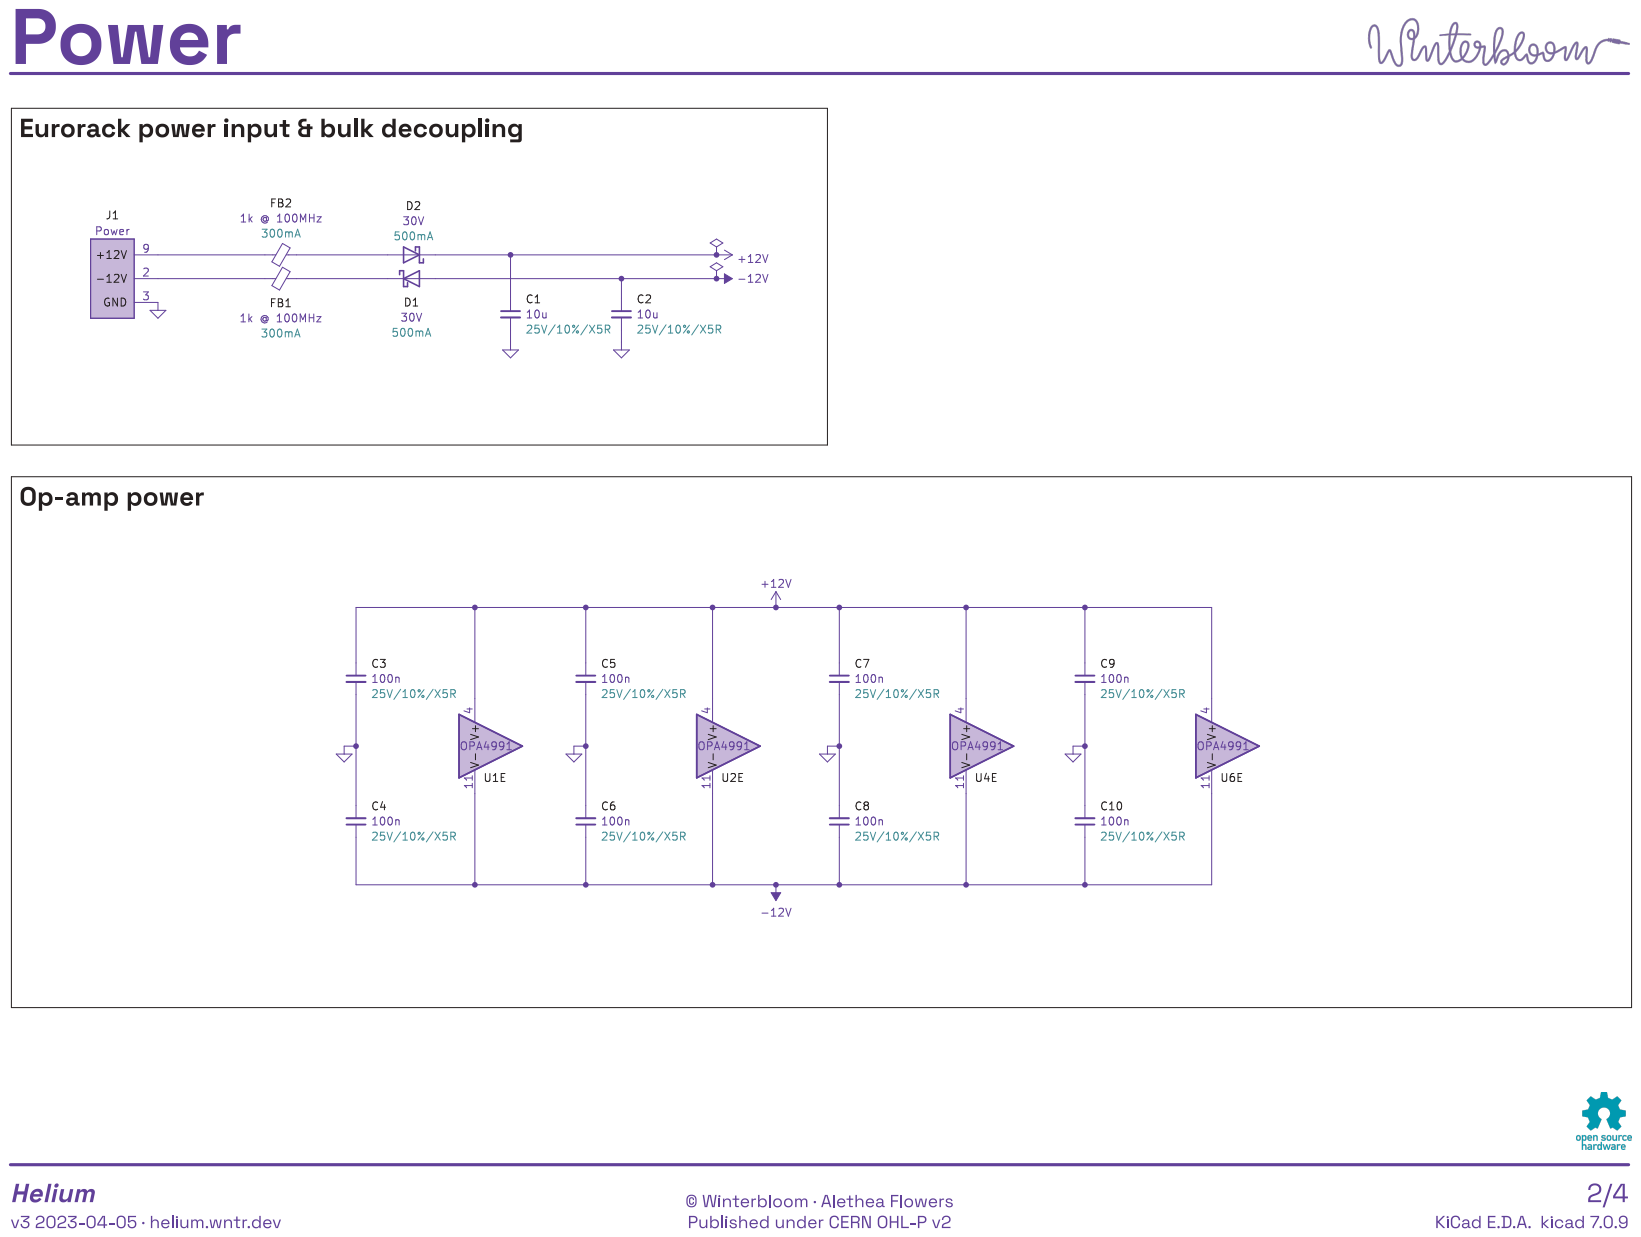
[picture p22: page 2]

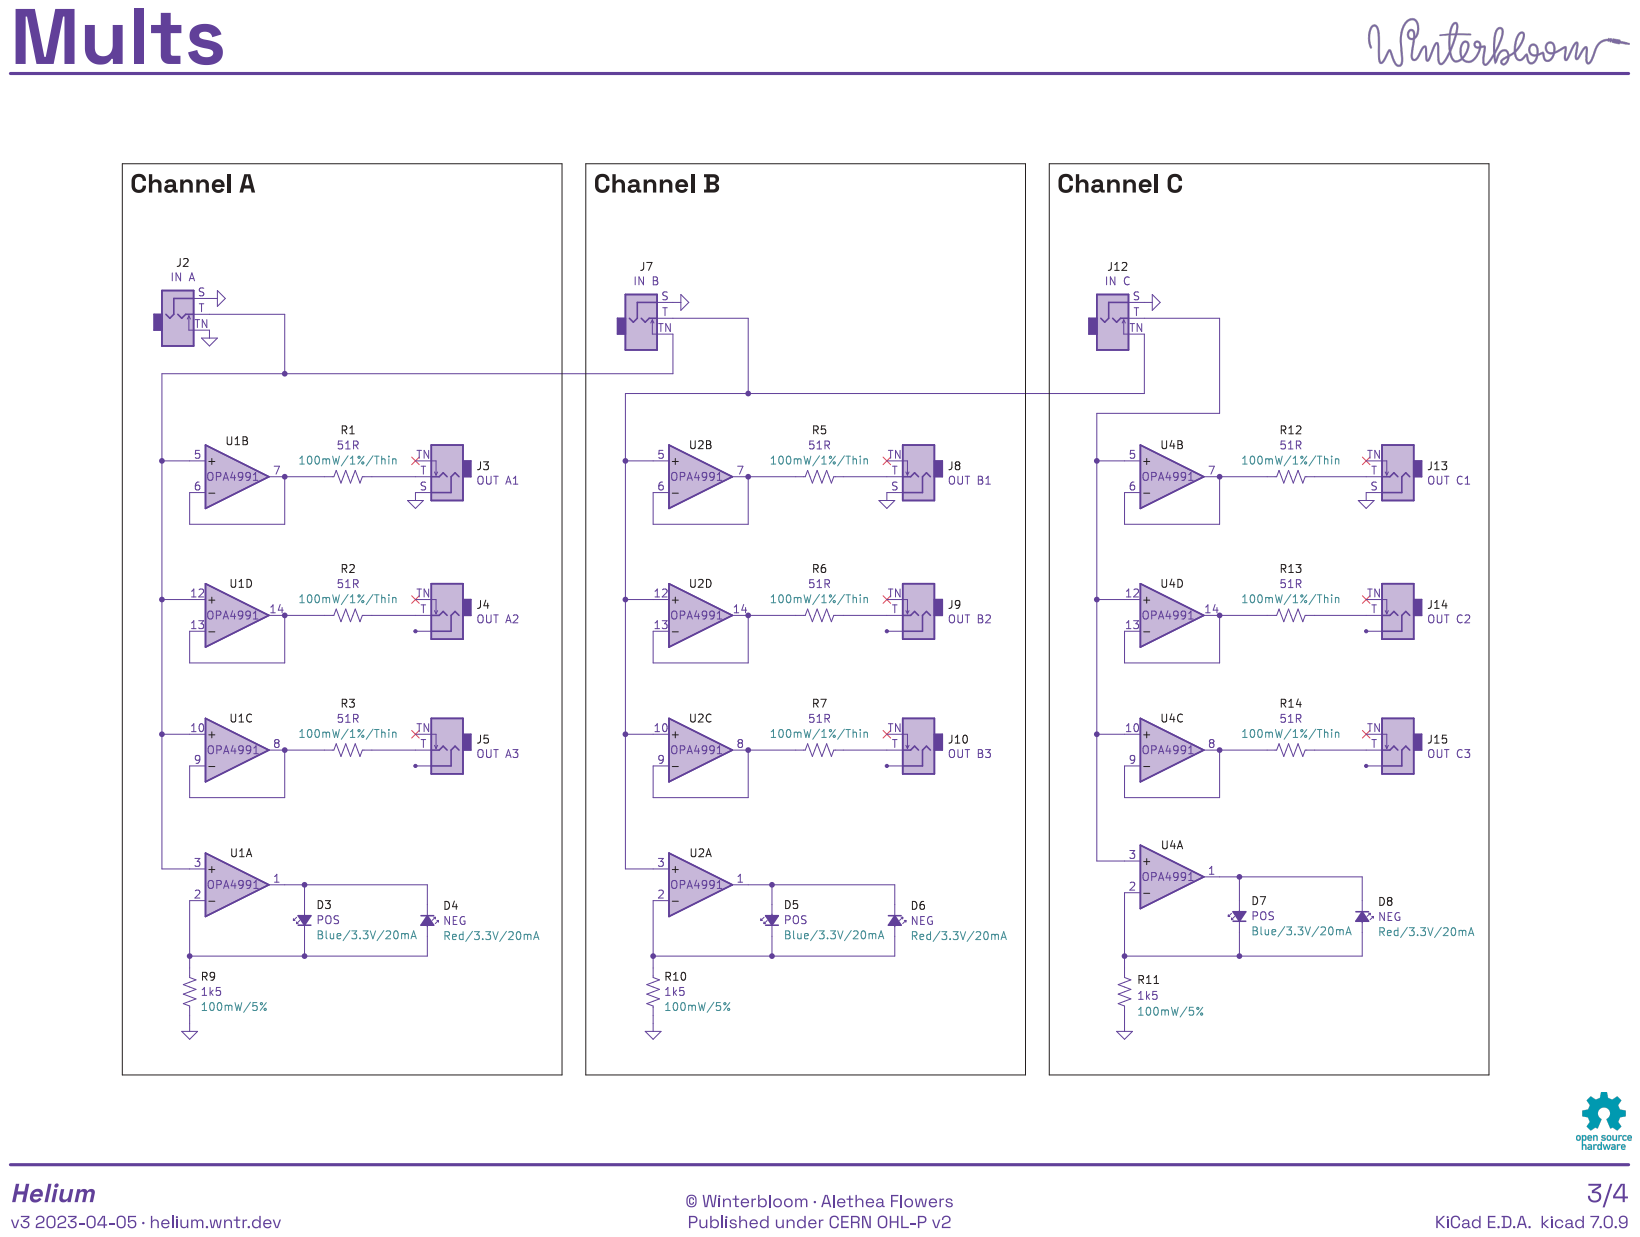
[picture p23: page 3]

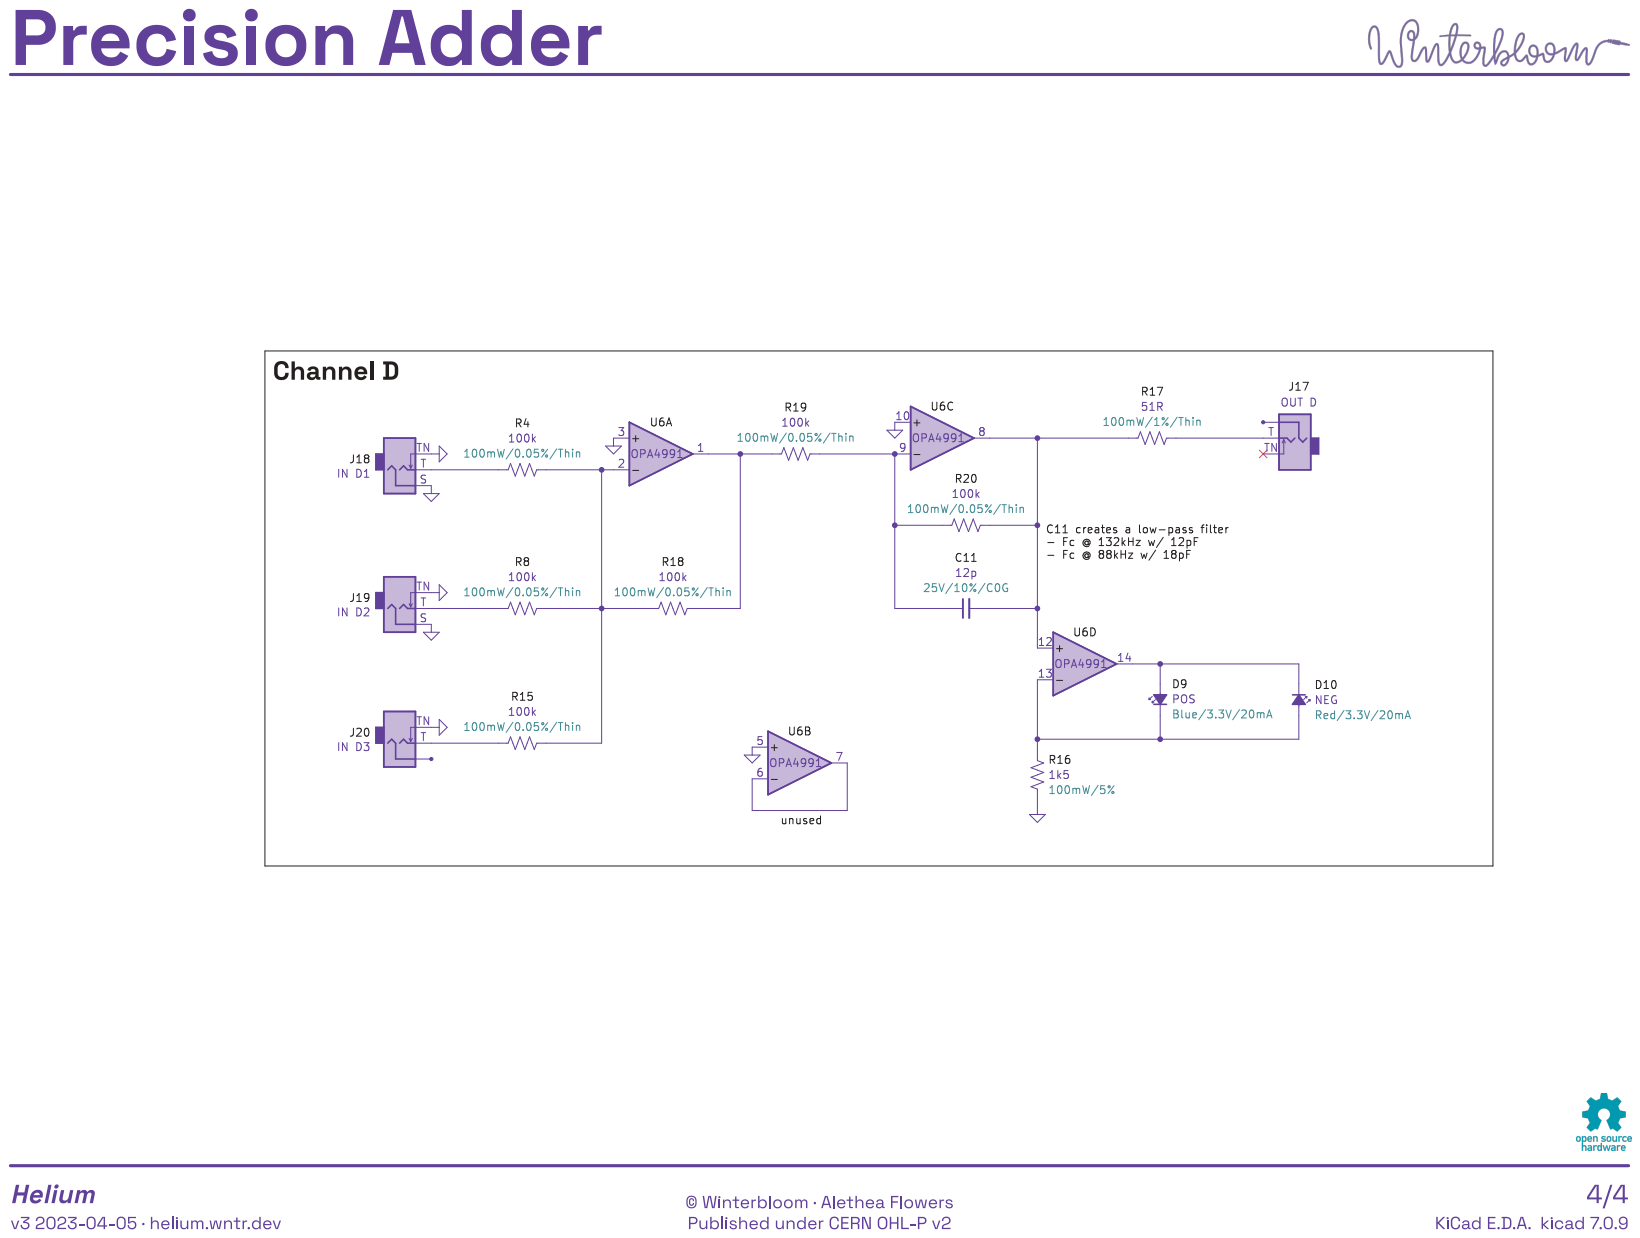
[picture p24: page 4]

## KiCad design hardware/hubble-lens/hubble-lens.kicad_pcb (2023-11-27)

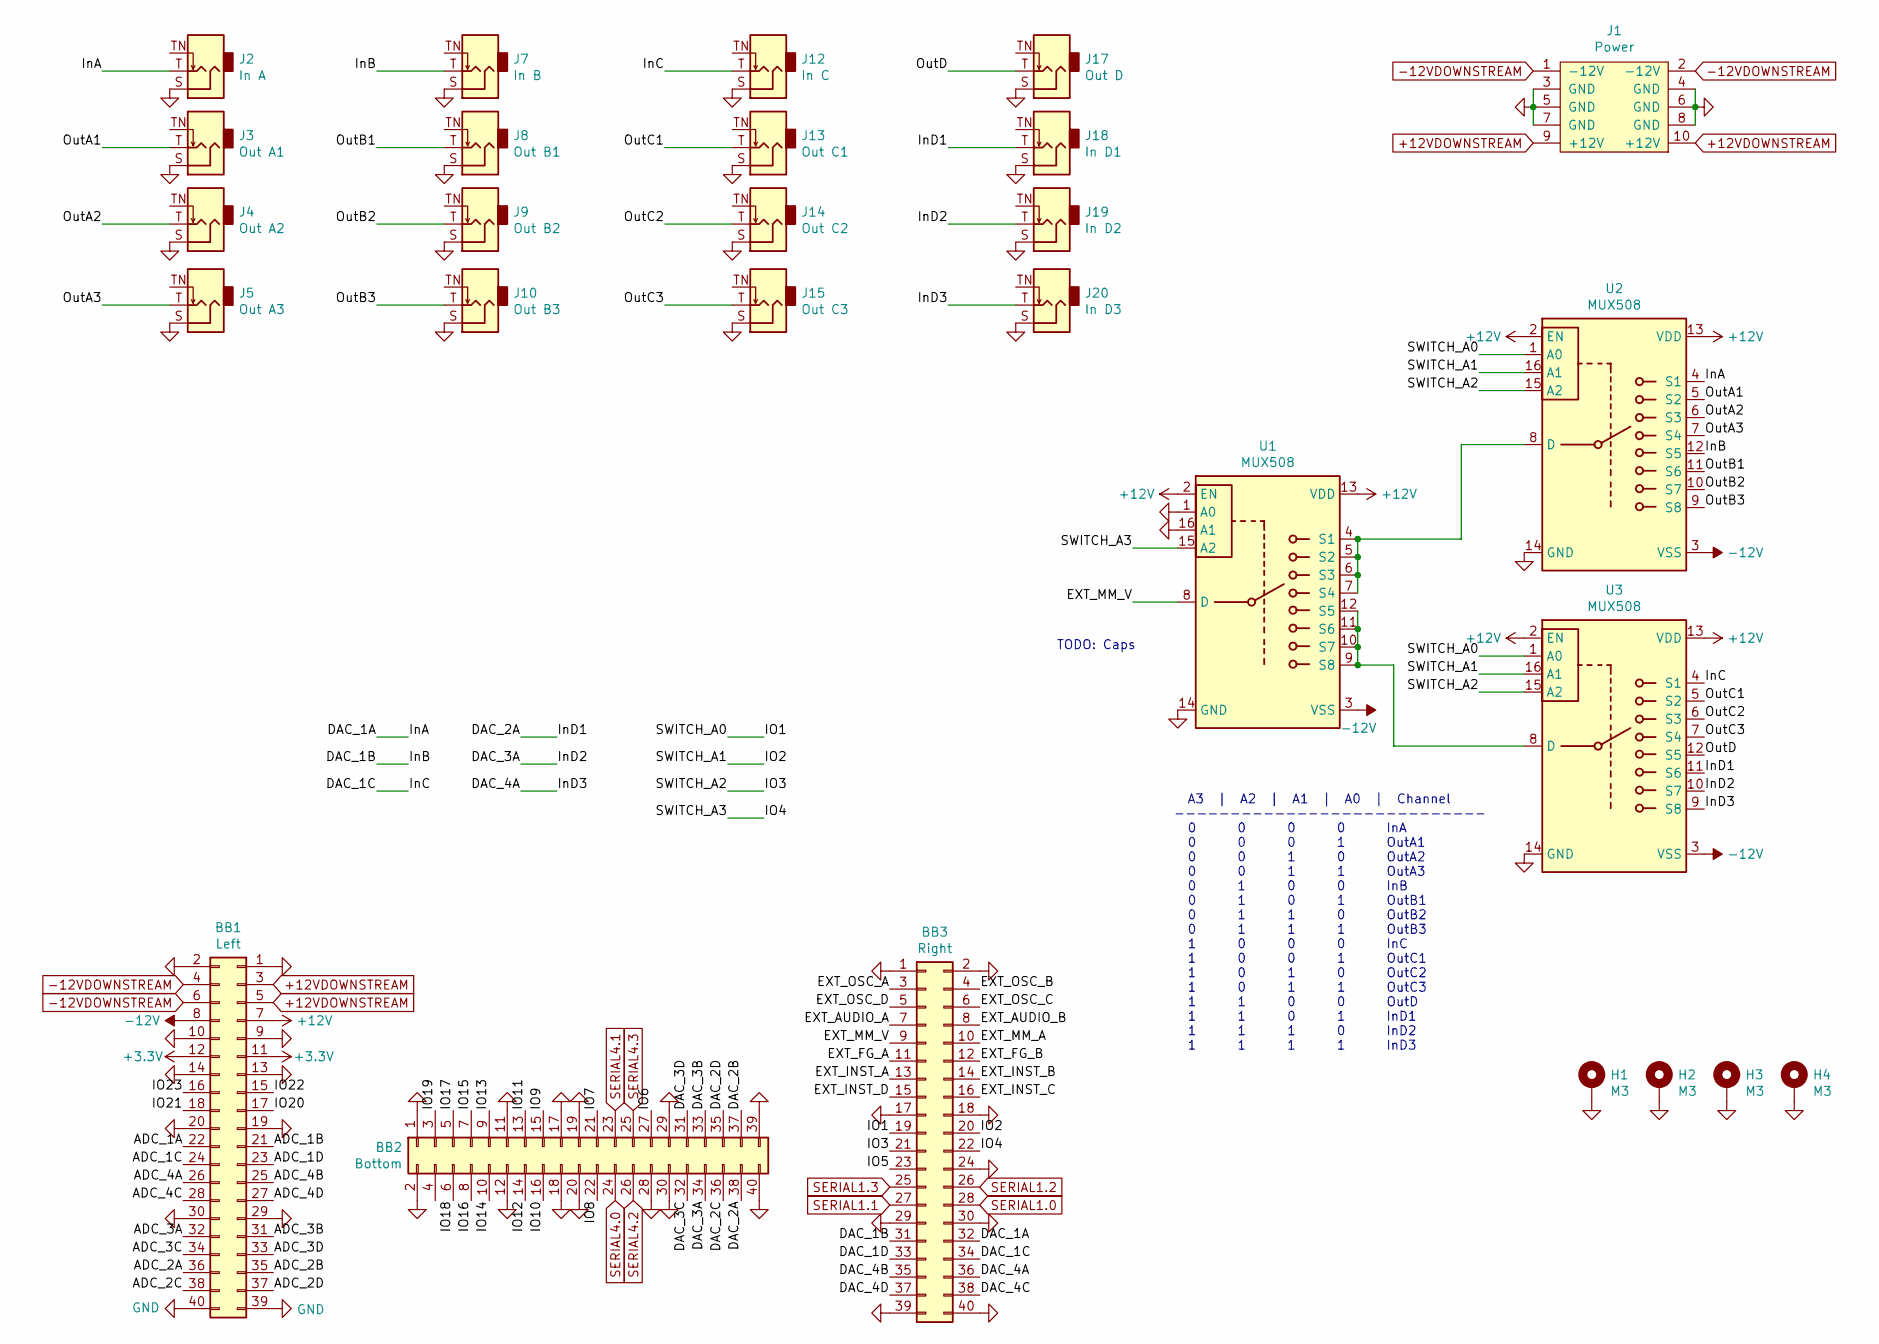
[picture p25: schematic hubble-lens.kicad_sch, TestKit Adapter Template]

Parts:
BB1: Left; PinSocket_2x20_P2.54mm_Vertical
BB2: Bottom; PinSocket_2x20_P2.54mm_Vertical
BB3: Right; PinSocket_2x20_P2.54mm_Vertical
H1, H2, H3, H4: M3; MountingHole_3.2mm_M3_Pad_Via
J1: Power; Eurorack_Power; mpn 302-S101
J2: In A; WQP-WQP518MA-skinny; mpn WQP-WQP518MA
J3: Out A1; WQP-WQP518MA-skinny; mpn WQP-WQP518MA
J4: Out A2; WQP-WQP518MA-skinny; mpn WQP-WQP518MA
J5: Out A3; WQP-WQP518MA-skinny; mpn WQP-WQP518MA
J7: In B; WQP-WQP518MA-skinny; mpn WQP-WQP518MA
J8: Out B1; WQP-WQP518MA-skinny; mpn WQP-WQP518MA
J9: Out B2; WQP-WQP518MA-skinny; mpn WQP-WQP518MA
J10: Out B3; WQP-WQP518MA-skinny; mpn WQP-WQP518MA
J12: In C; WQP-WQP518MA-skinny; mpn WQP-WQP518MA
J13: Out C1; WQP-WQP518MA-skinny; mpn WQP-WQP518MA
J14: Out C2; WQP-WQP518MA-skinny; mpn WQP-WQP518MA
J15: Out C3; WQP-WQP518MA-skinny; mpn WQP-WQP518MA
J17: Out D; WQP-WQP518MA-skinny; mpn WQP-WQP518MA
J18: In D1; WQP-WQP518MA-skinny; mpn WQP-WQP518MA
J19: In D2; WQP-WQP518MA-skinny; mpn WQP-WQP518MA
J20: In D3; WQP-WQP518MA-skinny; mpn WQP-WQP518MA
U1, U2, U3: MUX508; TSSOP-16_4.4x5mm_P0.65mm

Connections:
+3V3: BB1.11, BB1.12
+12V: BB1.7, U1.2 (EN), U1.13 (VDD), U2.2 (EN), U2.13 (VDD), U3.2 (EN), U3.13 (VDD)
+12VDOWNSTREAM: BB1.3, BB1.5, J1.9 (+12V), J1.10 (+12V)
-12V: BB1.8, U1.3 (VSS), U2.3 (VSS), U3.3 (VSS)
-12VDOWNSTREAM: BB1.4, BB1.6, J1.1 (-12V), J1.2 (-12V)
/ADC_1A: BB1.22
/ADC_1B: BB1.21
/ADC_1C: BB1.24
/ADC_1D: BB1.23
/ADC_2A: BB1.36
/ADC_2B: BB1.35
/ADC_2C: BB1.38
/ADC_2D: BB1.37
/ADC_3A: BB1.32
/ADC_3B: BB1.31
/ADC_3C: BB1.34
/ADC_3D: BB1.33
/ADC_4A: BB1.26
/ADC_4B: BB1.25
/ADC_4C: BB1.28
/ADC_4D: BB1.27
/DAC_1A: BB3.32, J2.T (Tip), U2.4 (S1)
/DAC_1B: BB3.31, J7.T (Tip), U2.12 (S5)
/DAC_1C: BB3.34, J12.T (Tip), U3.4 (S1)
/DAC_1D: BB3.33
/DAC_2A: BB2.38, J18.T (Tip), U3.11 (S6)
/DAC_2B: BB2.37
/DAC_2C: BB2.36
/DAC_2D: BB2.35
/DAC_3A: BB2.34, J19.T (Tip), U3.10 (S7)
/DAC_3B: BB2.33
/DAC_3C: BB2.32
/DAC_3D: BB2.31
/DAC_4A: BB3.36, J20.T (Tip), U3.9 (S8)
/DAC_4B: BB3.35
/DAC_4C: BB3.38
/DAC_4D: BB3.37
/EXT_AUDIO_A: BB3.7
/EXT_AUDIO_B: BB3.8
/EXT_FG_A: BB3.11
/EXT_FG_B: BB3.12
/EXT_INST_A: BB3.13
/EXT_INST_B: BB3.14
/EXT_INST_C: BB3.16
/EXT_INST_D: BB3.15
/EXT_MM_A: BB3.10
/EXT_MM_V: BB3.9, U1.8 (D)
/EXT_OSC_A: BB3.3
/EXT_OSC_B: BB3.4
/EXT_OSC_C: BB3.6
/EXT_OSC_D: BB3.5
/IO1: BB3.19, U2.1 (A0), U3.1 (A0)
/IO2: BB3.20, U2.16 (A1), U3.16 (A1)
/IO3: BB3.21, U2.15 (A2), U3.15 (A2)
/IO4: BB3.22, U1.15 (A2)
/IO5: BB3.23
/IO6: BB2.27
/IO7: BB2.21
/IO8: BB2.22
/IO9: BB2.15
/IO10: BB2.16
/IO11: BB2.13
/IO12: BB2.14
/IO13: BB2.9
/IO14: BB2.10
/IO15: BB2.7
/IO16: BB2.8
/IO17: BB2.5
/IO18: BB2.6
/IO19: BB2.3
/IO20: BB1.17
/IO21: BB1.18
/IO22: BB1.15
/IO23: BB1.16
/OutA1: J3.T (Tip), U2.5 (S2)
/OutA2: J4.T (Tip), U2.6 (S3)
/OutA3: J5.T (Tip), U2.7 (S4)
/OutB1: J8.T (Tip), U2.11 (S6)
/OutB2: J9.T (Tip), U2.10 (S7)
/OutB3: J10.T (Tip), U2.9 (S8)
/OutC1: J13.T (Tip), U3.5 (S2)
/OutC2: J14.T (Tip), U3.6 (S3)
/OutC3: J15.T (Tip), U3.7 (S4)
/OutD: J17.T (Tip), U3.12 (S5)
GND: BB1.1, BB1.2, BB1.9, BB1.10, BB1.13, BB1.14, BB1.19, BB1.20, BB1.29, BB1.30, BB1.39, BB1.40, BB2.1, BB2.2, BB2.11, BB2.12, BB2.17, BB2.18, BB2.19, BB2.20, BB2.28, BB2.29, BB2.30, BB2.39, BB2.40, BB3.1, BB3.2, BB3.17, BB3.18, BB3.24, BB3.29, BB3.30, BB3.39, BB3.40, H1.1, H2.1, H3.1, H4.1, J1.3 (GND), J1.4 (GND), J1.5 (GND), J1.6 (GND), J1.7 (GND), J1.8 (GND), J2.S (Sleeve), J3.S (Sleeve), J4.S (Sleeve), J5.S (Sleeve), J7.S (Sleeve), J8.S (Sleeve), J9.S (Sleeve), J10.S (Sleeve), J12.S (Sleeve), J13.S (Sleeve), J14.S (Sleeve), J15.S (Sleeve), J17.S (Sleeve), J18.S (Sleeve), J19.S (Sleeve), J20.S (Sleeve), U1.1 (A0), U1.14 (GND), U1.16 (A1), U2.14 (GND), U3.14 (GND)
unnamed: U1.4 (S1), U1.5 (S2), U1.6 (S3), U1.7 (S4), U2.8 (D)
unnamed: U1.9 (S8), U1.10 (S7), U1.11 (S6), U1.12 (S5), U3.8 (D)
SERIAL1.0: BB3.28
SERIAL1.1: BB3.27
SERIAL1.2: BB3.26
SERIAL1.3: BB3.25
SERIAL4.0: BB2.24
SERIAL4.1: BB2.23
SERIAL4.2: BB2.26
SERIAL4.3: BB2.25

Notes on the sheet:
A3 | A2 | A1 | A0 | Channel ---------------------------- 0 0 0 0 InA 0 0 0 1 OutA1 0 0 1 0 OutA2 0 0 1 1 OutA3 0 1 0 0 InB 0 1 0 1 OutB1 0 1 1 0 OutB2 0 1 1 1 OutB3 1 0 0 0 InC 1 0 0 1 OutC1 1 0 1 0 OutC2 1 0 1 1 OutC3 1 1 0 0 OutD 1 1 0 1 InD1 1 1 1 0 InD2 1 1 1 1 InD3
TODO: Caps

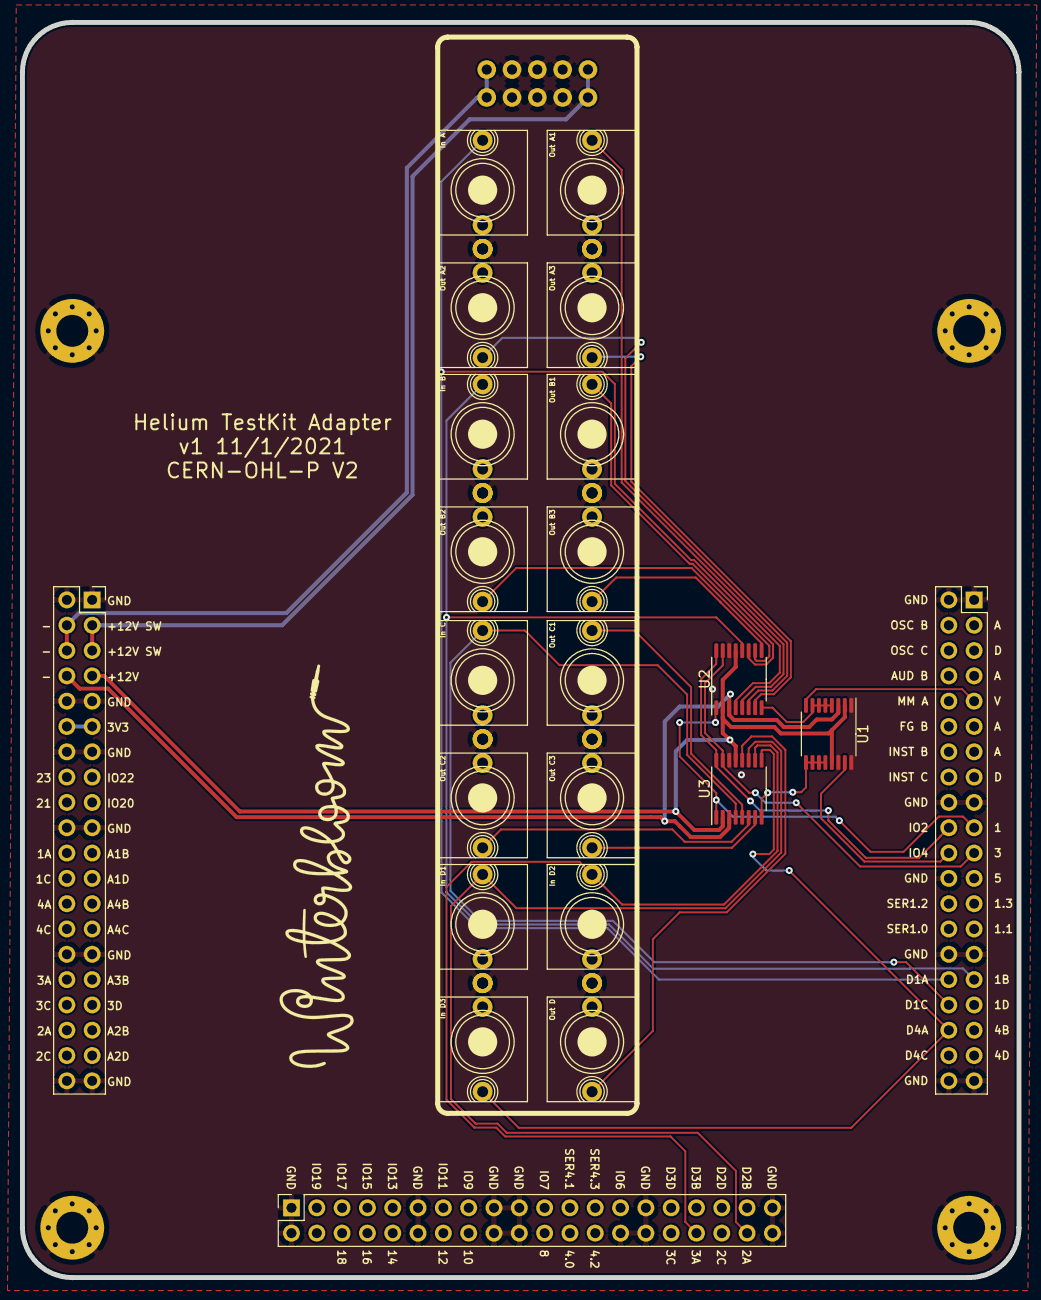
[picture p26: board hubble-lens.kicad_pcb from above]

Board: 2 copper layers, 100.0 x 126.0 mm, 27 parts (1 on the bottom side), 29 nets.

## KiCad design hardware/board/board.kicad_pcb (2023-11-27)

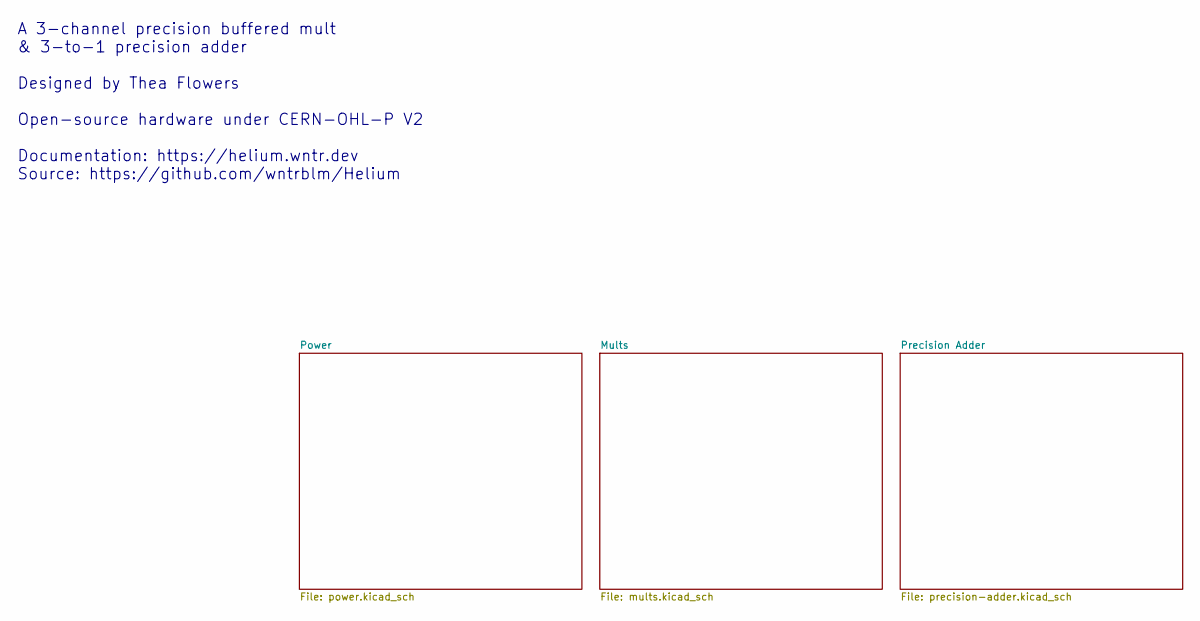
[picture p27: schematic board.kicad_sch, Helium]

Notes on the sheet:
A 3-channel precision buffered mult & 3-to-1 precision adder Designed by Thea Flowers Open-source hardware under CERN-OHL-P V2 Documentation: https://helium.wntr.dev Source: https://github.com/wntrblm/Helium

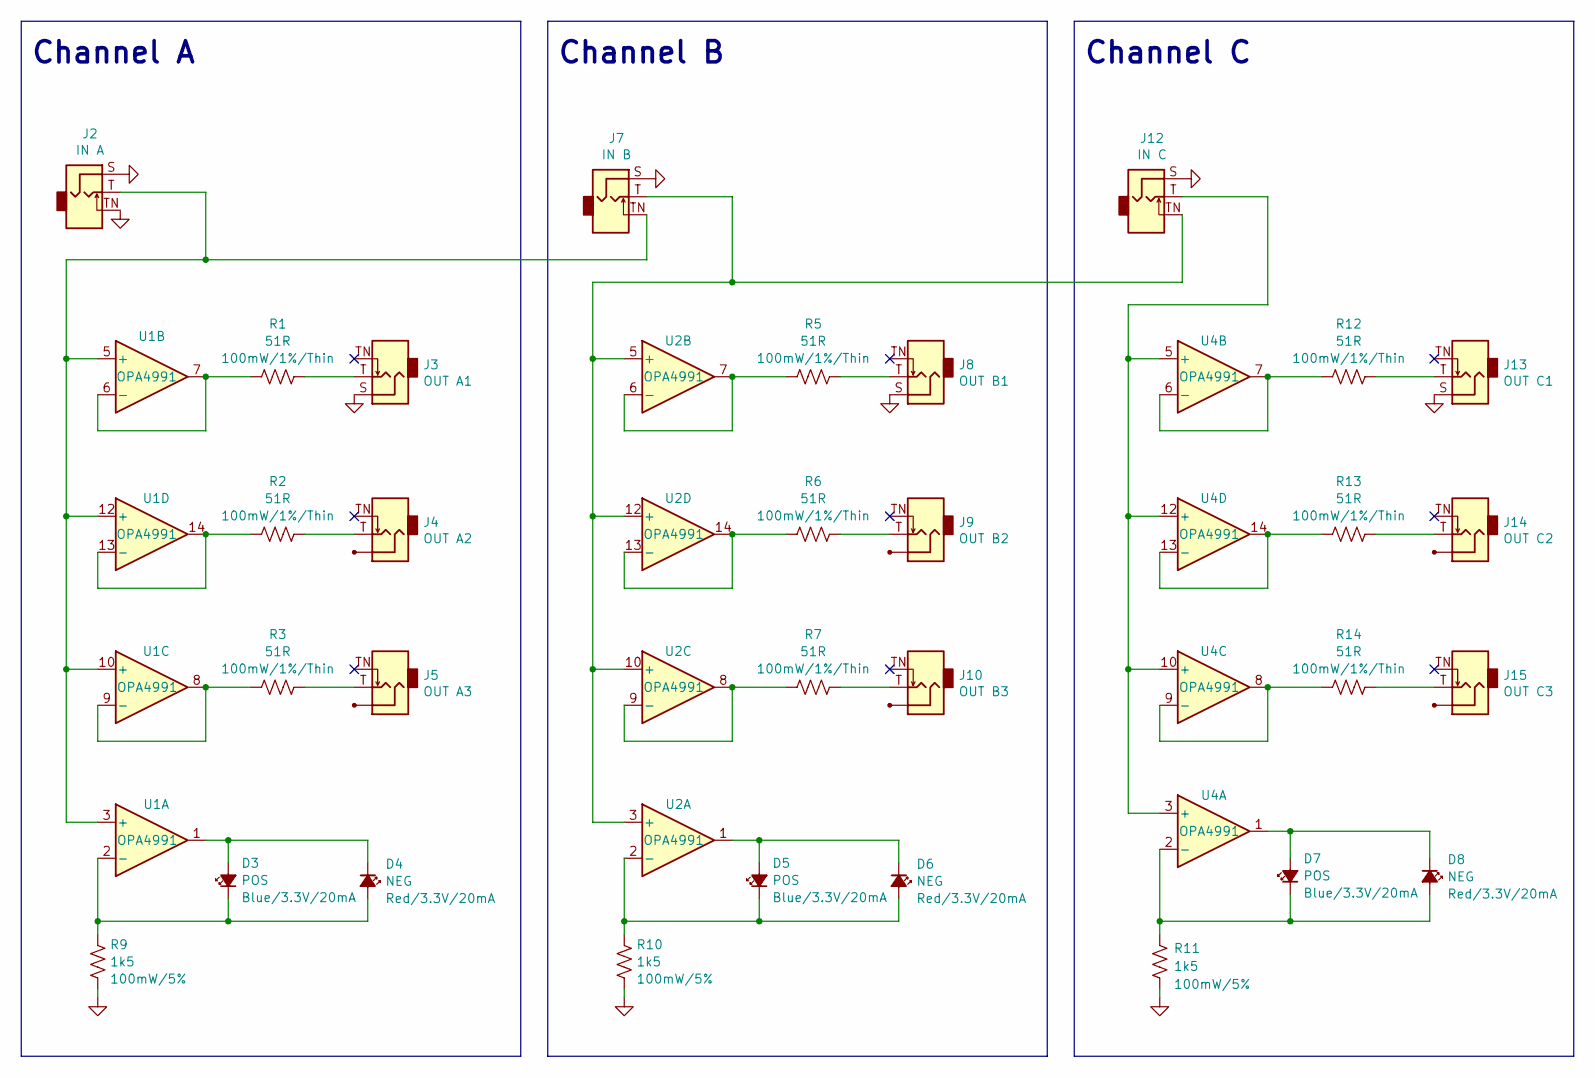
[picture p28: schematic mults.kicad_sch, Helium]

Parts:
D3, D5, D7: POS; LED_0805_Kingbright_APT2012; Rating Blue/3.3V/20mA; MPN APT2012VBC/D; DigiKey 754-1794-1-ND
D4, D6, D8: NEG; LED_0805_Kingbright_APT2012; Rating Red/3.3V/20mA; MPN APT2012SURCK; DigiKey 754-1133-1-ND
J2: IN A; AudioJack_WQP518MA_Compact_S; MPN WQP-WQP518MA
J3: OUT A1; AudioJack_WQP518MA_Compact_S; MPN WQP-WQP518MA
J4: OUT A2; AudioJack_WQP518MA_No_S; MPN WQP-WQP518MA
J5: OUT A3; AudioJack_WQP518MA_No_S; MPN WQP-WQP518MA
J7: IN B; AudioJack_WQP518MA_Compact_S; MPN WQP-WQP518MA
J8: OUT B1; AudioJack_WQP518MA_Compact_S; MPN WQP-WQP518MA
J9: OUT B2; AudioJack_WQP518MA_No_S; MPN WQP-WQP518MA
J10: OUT B3; AudioJack_WQP518MA_No_S; MPN WQP-WQP518MA
J12: IN C; AudioJack_WQP518MA_Compact_S; MPN WQP-WQP518MA
J13: OUT C1; AudioJack_WQP518MA_Compact_S; MPN WQP-WQP518MA
J14: OUT C2; AudioJack_WQP518MA_No_S; MPN WQP-WQP518MA
J15: OUT C3; AudioJack_WQP518MA_No_S; MPN WQP-WQP518MA
R1, R2, R3, R5, R6, R7, R12, R13, R14: 51R; R_0603_HandSolder; Rating 100mW/1%/Thin; MPN RT0603FRE0751RL; DigiKey 13-RT0603FRE0751RLCT-ND
R9, R10, R11: 1k5; R_0603_HandSolder; Rating 100mW/5%; MPN RC0603JR-071K5L; DigiKey 311-1.5KGRCT-ND
U1, U2, U4: OPA4991; TSSOP-14_4.4x5mm_P0.65mm; MPN OPA4991IPWR; DigiKey 296-OPA4991IPWRCT-ND

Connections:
GND: J2.S (Sleeve), J2.TN (Tip_normalize), J3.S (Sleeve), J7.S (Sleeve), J8.S (Sleeve), J12.S (Sleeve), J13.S (Sleeve), R9.1, R10.1, R11.1; also elsewhere on the board
unnamed: D3.2 (A), D4.1 (K), U1.1
unnamed: D3.1 (K), D4.2 (A), R9.2, U1.2 (-)
unnamed: D5.2 (A), D6.1 (K), U2.1
unnamed: D5.1 (K), D6.2 (A), R10.2, U2.2 (-)
unnamed: D7.2 (A), D8.1 (K), U4.1
unnamed: D7.1 (K), D8.2 (A), R11.2, U4.2 (-)
unnamed: J2.T (Tip), J7.TN (Tip_normalize), U1.3 (+), U1.5 (+), U1.10 (+), U1.12 (+)
unnamed: J3.T (Tip), R1.1
unnamed: J4.T (Tip), R2.1
unnamed: J5.T (Tip), R3.1
unnamed: J8.T (Tip), R5.1
unnamed: J9.T (Tip), R6.1
unnamed: J10.T (Tip), R7.1
unnamed: J12.T (Tip), U4.3 (+), U4.5 (+), U4.10 (+), U4.12 (+)
unnamed: J7.T (Tip), J12.TN (Tip_normalize), U2.3 (+), U2.5 (+), U2.10 (+), U2.12 (+)
unnamed: J13.T (Tip), R12.1
unnamed: J14.T (Tip), R13.1
unnamed: J15.T (Tip), R14.1
unnamed: R1.2, U1.6 (-), U1.7
unnamed: R3.2, U1.8, U1.9 (-)
unnamed: R2.2, U1.13 (-), U1.14
unnamed: R5.2, U2.6 (-), U2.7
unnamed: R7.2, U2.8, U2.9 (-)
unnamed: R6.2, U2.13 (-), U2.14
unnamed: R12.2, U4.6 (-), U4.7
unnamed: R14.2, U4.8, U4.9 (-)
unnamed: R13.2, U4.13 (-), U4.14

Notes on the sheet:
Channel C
Channel B
Channel A

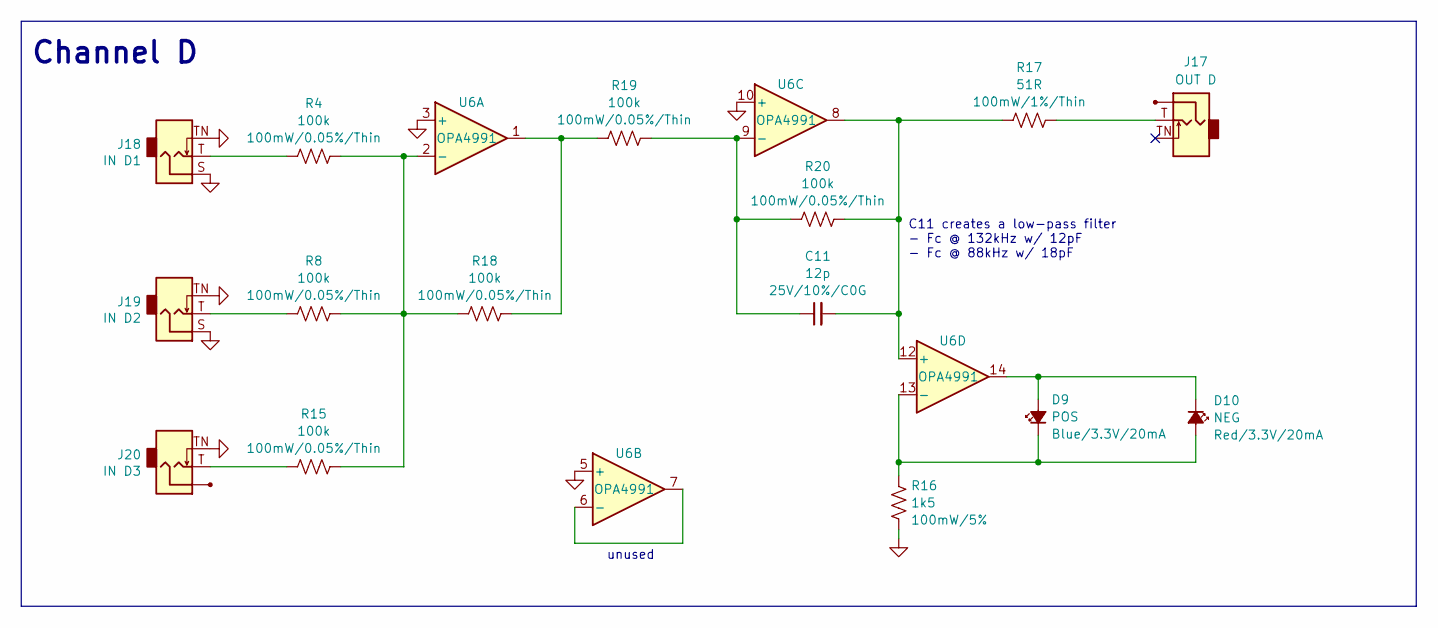
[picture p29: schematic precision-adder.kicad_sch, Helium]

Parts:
C11: 12p; C_0603_HandSolder; Rating 25V/10%/C0G; MPN CC0603JPNPO9BN120; DigiKey 13-CC0603JPNPO9BN120CT-ND
D9: POS; LED_0805_Kingbright_APT2012; Rating Blue/3.3V/20mA; MPN APT2012VBC/D; DigiKey 754-1794-1-ND
D10: NEG; LED_0805_Kingbright_APT2012; Rating Red/3.3V/20mA; MPN APT2012SURCK; DigiKey 754-1133-1-ND
J17: OUT D; AudioJack_WQP518MA_No_S; MPN WQP-WQP518MA
J18: IN D1; AudioJack_WQP518MA_Compact_S; MPN WQP-WQP518MA
J19: IN D2; AudioJack_WQP518MA_Compact_S; MPN WQP-WQP518MA
J20: IN D3; AudioJack_WQP518MA_No_S; MPN WQP-WQP518MA
R4, R8, R15, R18, R19, R20: 100k; R_0603_HandSolder; Rating 100mW/0.05%/Thin; MPN RG1608N-104-W-T1; DigiKey RG16N100KWCT-ND
R16: 1k5; R_0603_HandSolder; Rating 100mW/5%; MPN RC0603JR-071K5L; DigiKey 311-1.5KGRCT-ND
R17: 51R; R_0603_HandSolder; Rating 100mW/1%/Thin; MPN RT0603FRE0751RL; DigiKey 13-RT0603FRE0751RLCT-ND
U6: OPA4991; TSSOP-14_4.4x5mm_P0.65mm; MPN OPA4991IPWR; DigiKey 296-OPA4991IPWRCT-ND

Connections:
GND: J18.S (Sleeve), J18.TN (Tip_normalize), J19.S (Sleeve), J19.TN (Tip_normalize), J20.TN (Tip_normalize), R16.1, U6.3 (+), U6.5 (+), U6.10 (+); also elsewhere on the board
unnamed: D9.1 (K), D10.2 (A), R16.2, U6.13 (-)
unnamed: D9.2 (A), D10.1 (K), U6.14
unnamed: J17.T (Tip), R17.1
unnamed: J18.T (Tip), R4.2
unnamed: J19.T (Tip), R8.2
unnamed: J20.T (Tip), R15.2
unnamed: R18.1, R19.2, U6.1
unnamed: R4.1, R8.1, R15.1, R18.2, U6.2 (-)
unnamed: U6.6 (-), U6.7
unnamed: C11.1, R19.1, R20.2, U6.9 (-)
unnamed: C11.2, R17.2, R20.1, U6.8, U6.12 (+)

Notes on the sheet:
unused
C11 creates a low-pass filter - Fc @ 132kHz w/ 12pF - Fc @ 88kHz w/ 18pF
Channel D

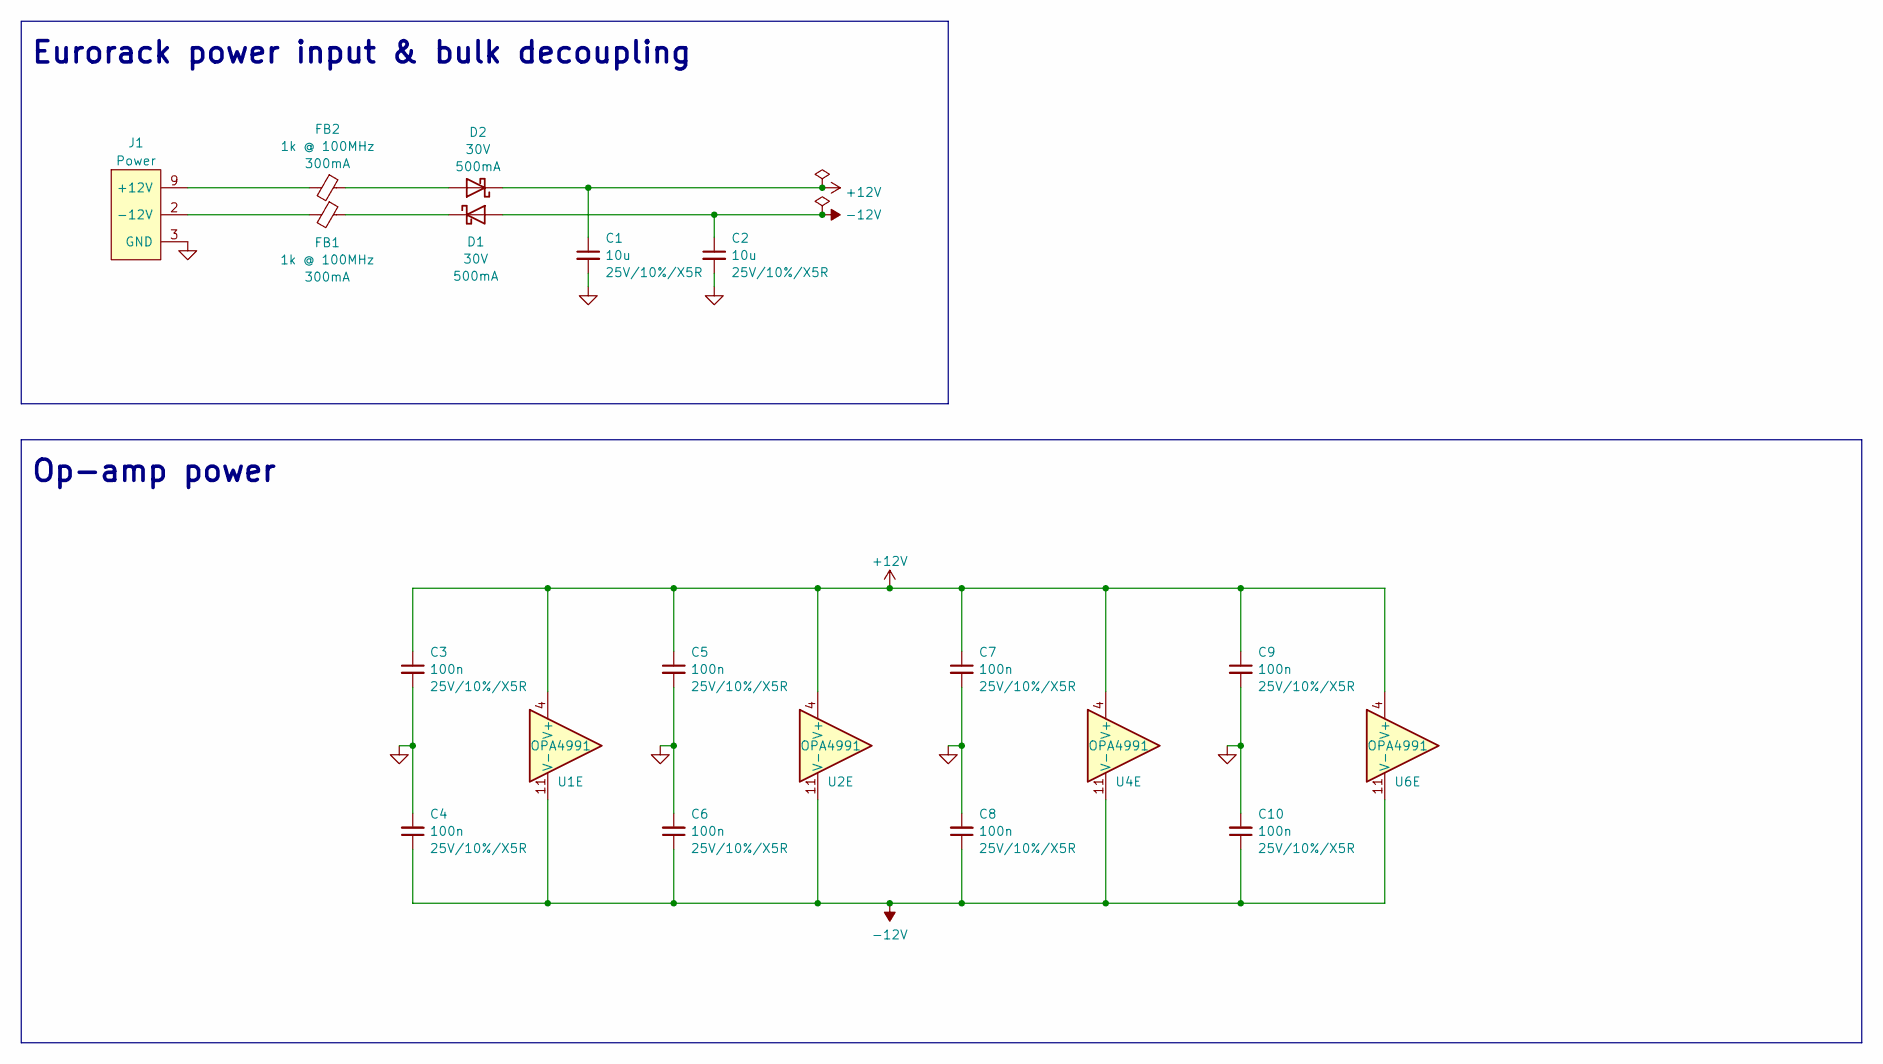
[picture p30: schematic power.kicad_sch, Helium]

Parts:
C1, C2: 10u; C_0805_HandSolder; Rating 25V/10%/X5R; MPN GRM21BR61E106KA73K; DigiKey 490-16824-1-ND
C3, C4, C5, C6, C7, C8, C9, C10: 100n; C_0603_HandSolder; Rating 25V/10%/X5R; MPN CL10B104KB8NNNC; DigiKey 1276-1000-2-ND
D1, D2: 30V; D_SOD-123+SOD-123F; Rating 500mA; MPN PMEG2005EGWX; DigiKey 1727-7329-1-ND
FB1, FB2: 1k @ 100MHz; L_0603_HandSolder; Rating 300mA; MPN BLM18AG102SN1D; DigiKey 490-1015-1-ND
J1: Power; Eurorack_Power_2x5_Shrouded_Lock; MPN 302-S101; DigiKey ED1543-ND
U1, U2, U4, U6: OPA4991; TSSOP-14_4.4x5mm_P0.65mm; MPN OPA4991IPWR; DigiKey 296-OPA4991IPWRCT-ND

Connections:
+12V: C1.1, C3.1, C5.1, C7.1, C9.1, D2.1 (K), U1.4 (V+), U2.4 (V+), U4.4 (V+), U6.4 (V+)
-12V: C2.1, C4.1, C6.1, C8.1, C10.1, D1.2 (A), U1.11 (V-), U2.11 (V-), U4.11 (V-), U6.11 (V-)
GND: C1.2, C2.2, C3.2, C4.2, C5.2, C6.2, C7.2, C8.2, C9.2, C10.2, J1.3 (GND), J1.4 (GND), J1.5 (GND), J1.6 (GND), J1.7 (GND), J1.8 (GND); also elsewhere on the board
unnamed: D1.1 (K), FB1.1
unnamed: D2.2 (A), FB2.1
unnamed: FB1.2, J1.1 (-12V), J1.2 (-12V)
unnamed: FB2.2, J1.9 (+12V), J1.10 (+12V)

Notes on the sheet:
Eurorack power input & bulk decoupling
Op-amp power

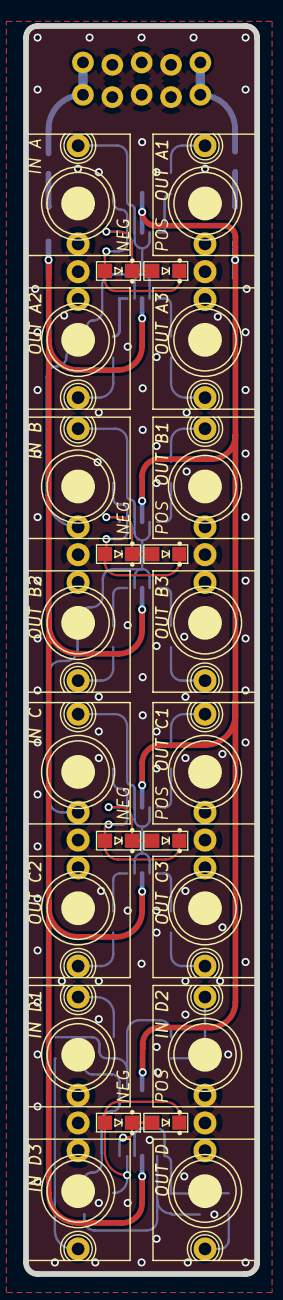
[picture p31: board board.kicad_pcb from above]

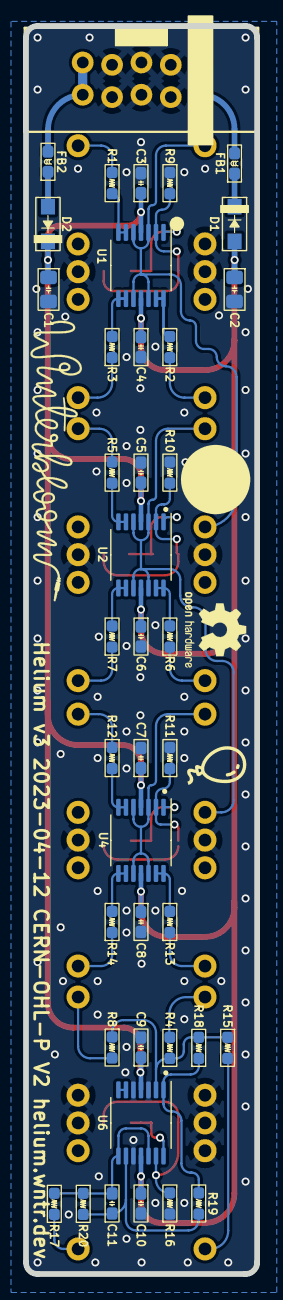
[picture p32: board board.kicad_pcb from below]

Board: 2 copper layers, 20.0 x 108.0 mm, 64 parts (40 on the bottom side), 45 nets.

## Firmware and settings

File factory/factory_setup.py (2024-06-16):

import itertools
import statistics
from time import sleep

import pyvisa
from rich import print
from wintertools import reportcard, thermalprinter
from wintertools.multimeter import Multimeter

from hubble import Hubble

rm = pyvisa.ResourceManager("@py")
mm = Multimeter(rm)
h = Hubble()


class Mux:
    IN_A = (0, 0, 0, 0)
    OUT_A1 = (0, 0, 0, 1)
    OUT_A2 = (0, 0, 1, 0)
    OUT_A3 = (0, 0, 1, 1)
    IN_B = (0, 1, 0, 0)
    OUT_B1 = (0, 1, 0, 1)
    OUT_B2 = (0, 1, 1, 0)
    OUT_B3 = (0, 1, 1, 1)
    IN_C = (1, 0, 0, 0)
    OUT_C1 = (1, 0, 0, 1)
    OUT_C2 = (1, 0, 1, 0)
    OUT_C3 = (1, 0, 1, 1)
    OUT_D = (1, 1, 0, 0)
    IN_D1 = (1, 1, 0, 1)
    IN_D2 = (1, 1, 1, 0)
    IN_D3 = (1, 1, 1, 1)

    @staticmethod
    def set(addr):
        a3, a2, a1, a0 = addr
        h.IO1.value = a0
        h.IO2.value = a1
        h.IO3.value = a2
        h.IO4.value = a3

    @classmethod
    def measure(cls, addr):
        cls.set(addr)
        sleep(0.002)
        return mm.read_voltage_fast()
        return statistics.mean([mm.read_voltage_fast() for _ in range(3)])


class Voltage:
    IN_A = h.VOUT1A
    IN_B = h.VOUT1A
    IN_C = h.VOUT1C
    IN_D1 = h.VOUT2A
    IN_D2 = h.VOUT3A
    IN_D3 = h.VOUT4A


GRAPH = reportcard.LineGraph(
    width=1000,
    height=500,
    x_axis=reportcard.Axis(
        label="Input (V)", min=-7, min_label="-7", max=7, max_label="7"
    ),
    y_axis=reportcard.Axis(
        label="Error (mV)", min=-1, min_label="-1", max=1, max_label="1"
    ),
    grid_lines=reportcard.GridLines(
        x_step=1 / 14,
        y_step=1 / 4,
    ),
)
ADDER_GRAPH = reportcard.LineGraph(
    width=1000,
    height=500,
    x_axis=reportcard.Axis(
        label="Input (V)", min=-7, min_label="-7", max=7, max_label="7"
    ),
    y_axis=reportcard.Axis(
        label="Error (mV)", min=-50, min_label="-50", max=50, max_label="50"
    ),
    grid_lines=reportcard.GridLines(
        x_step=1 / 14,
        y_step=1 / 10,
    ),
)


def measure_channel(channel_name, dac, channel_ref_mux, channel_muxes):
    print(f"# Channel {channel_name}")
    series = reportcard.Series()

    for v in range(-8, 8):
        dac.voltage = v
        ref = Mux.measure(channel_ref_mux)

        measurements = []
        for n, mux in enumerate(channel_muxes):
            measured = Mux.measure(mux)
            measurements.append(measured)

        average_diff_mv = (ref - statistics.mean(measurements)) * 1_000
        series.data.append((v, average_diff_mv))

        print(
            f"{v=}, {ref=:0.5f},",
            ", ".join(f"{n}: {v:0.5f}" for n, v in enumerate(measurements, 1)),
        )

    overall_measurements = [offset for _, offset in series.data]
    overall_average = statistics.mean(overall_measurements)
    overall_stdev = statistics.stdev(overall_measurements)

    if overall_average < 1.0 and overall_stdev < 0.3:
        success = True
    else:
        success = False

    section = reportcard.Section(name=f"Channel {channel_name}")
    section.items.append(reportcard.PassFailItem(label="Offset error", value=success))
    section.items.append(
        reportcard.SubTextItem(text=f"Average: {overall_average:0.2f} mV")
    )
    section.items.append(reportcard.SubTextItem(text=f"Stdev: {overall_stdev:0.2f}"))
    section.items.append(
        reportcard.LineGraphItem(
            graph=GRAPH,
            series=series,
        )
    )

    return section


def measure_adder():
    print("# Channel D")

    input_series = []

    for dac, mux in [
        (Voltage.IN_D1, Mux.IN_D1),
        (Voltage.IN_D2, Mux.IN_D2),
        (Voltage.IN_D3, Mux.IN_D3),
    ]:
        Voltage.IN_D1.voltage = 0
        Voltage.IN_D2.voltage = 0
        Voltage.IN_D3.voltage = 0

        series = reportcard.Series()

        for v in range(-8, 8):
            dac.voltage = v
            ref = Mux.measure(mux)
            measured = Mux.measure(Mux.OUT_D)
            diff = (ref - measured) * 1_000
            print(f"{v=}, {ref=:0.5f}, {measured=:0.5f}, {diff=:0.2f} mV")
            series.data.append((v, diff))

        input_series.append(series)

    all_diffs = [x for _, x in itertools.chain(*[series.data for series in input_series])]
    c_c_stdev = statistics.stdev(all_diffs)

    if all([-50 < x < 50 for x in all_diffs]):
        offset_and_gain_success = True
    else:
        offset_and_gain_success = False

    if c_c_stdev < 10:
        c_c_success = True
    else:
        c_c_success = False

    section = reportcard.Section(name="Unity Mixer")
    section.items.append(
        reportcard.PassFailItem(
            label="Offset & gain error", value=offset_and_gain_success
        )
    )
    section.items.append(
        reportcard.PassFailItem(label="Channel-to-channel", value=c_c_success)
    )
    section.items.append(reportcard.SubTextItem(text=f"Stdev: {c_c_stdev:0.2f}"))
    section.items.append(
        reportcard.LineGraphItem(
            graph=ADDER_GRAPH,
            series=input_series,
        )
    )
    return section


if __name__ == "__main__":
    report = reportcard.Report(
        name="Helium",
    )

    channel_a_result = measure_channel(
        "A", Voltage.IN_A, Mux.IN_A, [Mux.OUT_A1, Mux.OUT_A2, Mux.OUT_A3]
    )
    report.sections.append(channel_a_result)

    channel_b_result = measure_channel(
        "B", Voltage.IN_B, Mux.IN_B, [Mux.OUT_B1, Mux.OUT_B2, Mux.OUT_B3]
    )
    report.sections.append(channel_b_result)

    channel_c_result = measure_channel(
        "C", Voltage.IN_C, Mux.IN_C, [Mux.OUT_C1, Mux.OUT_C2, Mux.OUT_C3]
    )
    report.sections.append(channel_c_result)

    adder_result = measure_adder()
    report.sections.append(adder_result)

    print(report)
    report.save()
    reportcard.render_html(report)

    if report.succeeded:
        h.success()
        print("PASSED")
    else:
        h.fail()
        print("FAILED")

    if report.succeeded:
        thermalprinter.print_me_maybe(reportcard.render_image(report))

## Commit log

2021-09-21 Initial versions
    [board.kicad_pcb, board.sch]
2021-10-03 Changes from tests on first revision
    1. Silkscreen legibility changes
    2. Added version numbers and such to page info blocks
    3. Change MPNs and values
    4. Change footprints for LEDs and Diodes.
    5. Pin one markers
    [board.kicad_pcb, board.sch]
2021-10-08 Rename folders
    [board.kicad_pcb, board.sch]
2021-10-08 Fix Hydrogen's page size
    [board.sch]
2021-10-08 Fix Helium's page size
    [board.sch]
2021-10-08 Add circle for QA sticker to Helium
    [board.kicad_pcb]
2021-10-08 Add circle for QA sticker to Hydrogen
    [board.kicad_pcb]
2021-10-10 Make trans rights bigger
    [board.kicad_pcb]
2021-10-26 Update hydrogen
    [board.kicad_pcb, board.sch]
2021-11-08 Remove hydrogen files
    [board.kicad_pcb, board.sch]
2021-11-08 Move board design into hardware/
    [board.kicad_pcb, board.sch]
2021-11-08 Add testkit adapter
    [helium-testkit.kicad_pcb, helium-testkit.sch]
2021-11-08 Update resistor values; create PDF
    [board.sch]
2021-11-16 Update values for resistors
    [board.kicad_pcb, board.sch]
2021-12-08 hardware: add laser design's for the testkit adapter board guide, pin holder, and pressure plate
2021-12-25 user guide: Add surface mount kit assembly guide
    [board.sch]
2021-12-28 hardware: convert to KiCAD 6, fix C2
    [board.kicad_pcb, board.kicad_sch, board.sch]
2021-12-28 hardware: update PDF of schematic
2022-01-08 user guide: Add kit assembly guide
2022-06-19 user guide: link to assembled and kit product pages
2023-02-26 Update KiCAD project to V7
    [board.kicad_pcb, board.kicad_sch]
2023-04-13 hardware: revision 3
    - Update to new Winterbloom footprints
    - Update to match current Winterbloom design standards
    - Re-route traces
    - Update legends
    [board.kicad_pcb, board.kicad_sch]
2023-06-25 hardware: set drill origin
    [board.kicad_pcb]
2023-06-29 factory: fix channel B measurements, modify acceptable results slightly based on real-world data
    [factory_setup.py]
2023-07-24 user guide: remove screws and power cable from kit contents
2023-11-27 hardware: Add faceplate design
    [faceplate.kicad_pcb]
2023-11-27 hardware: Changes for self-sourcing
    - Add manufacturer part numbers and DigiKey, Mouser, and LCSC part numbers for all BOM items.
    - Split schematic into multiple US letter-sized sheets.
    - Update to new Winterbloom drawing sheet.
    - Create new PDF of schematic.
    - Create gerbers.zip with pre-made Gerbers.
    [board.kicad_pcb, board.kicad_sch, mults.kicad_sch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]
2023-11-27 hardware: rename testkit-adapter to hubble-lens
    [helium-testkit.kicad_pcb, hubble-lens.kicad_pcb, hubble-lens.kicad_sch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]
2024-02-06 user guide: switch to Wintersong theme, replace illustrations with svgs
2024-02-23 user guide: you don't actually need a smol screwdriver to build this

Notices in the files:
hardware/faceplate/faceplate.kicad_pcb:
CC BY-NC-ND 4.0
